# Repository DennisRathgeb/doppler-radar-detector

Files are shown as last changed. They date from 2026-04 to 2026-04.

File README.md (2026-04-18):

# Doppler Radar Detector

> 24 GHz radar that measures distance (FMCW) and speed (CW Doppler), streams a live spectrum to a touchscreen UI, bridges telemetry over WiFi, and fuses the radar result with camera-based angle-of-arrival detection on a desktop application. ZHAW PM4 team project, spring 2025.











## Block Diagram

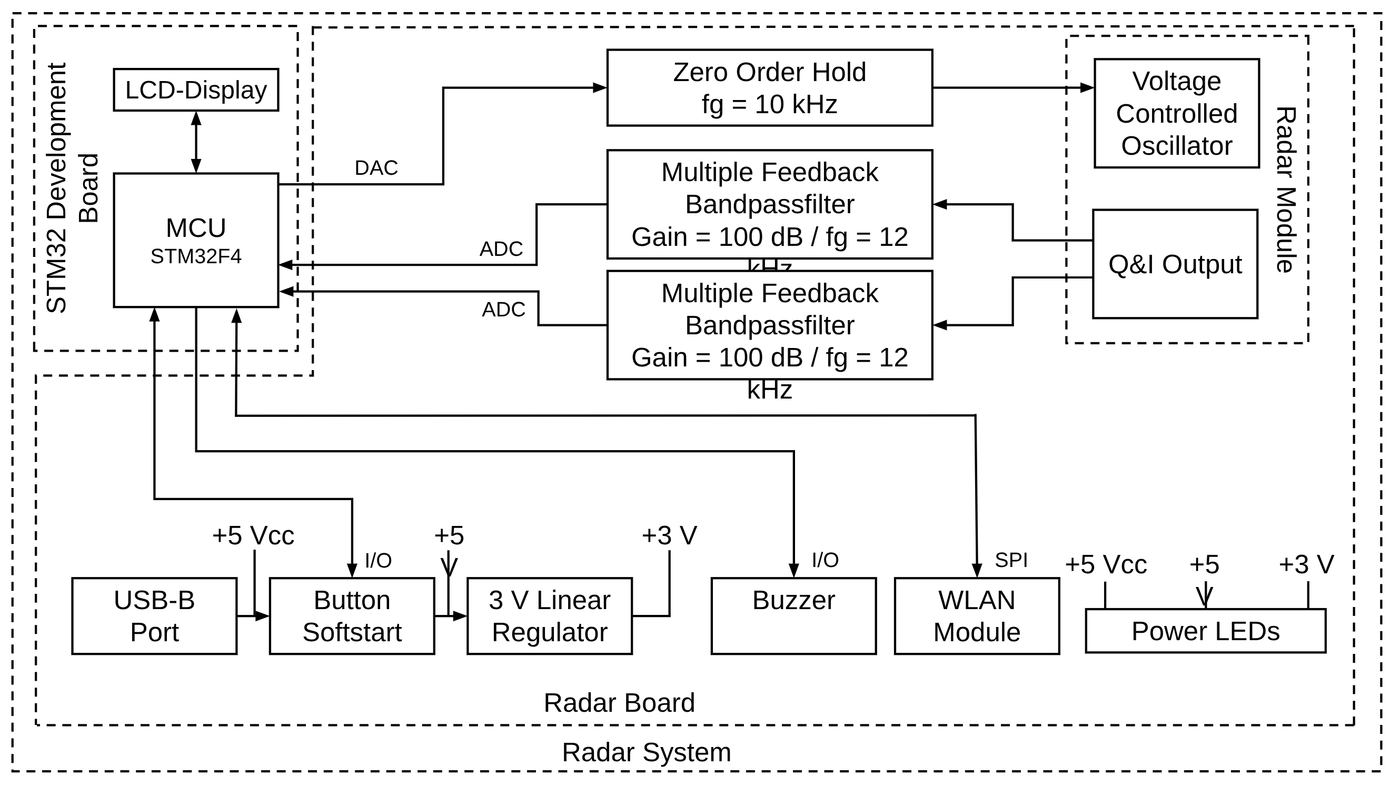
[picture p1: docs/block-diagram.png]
System block diagram


MCU-side signal flow:

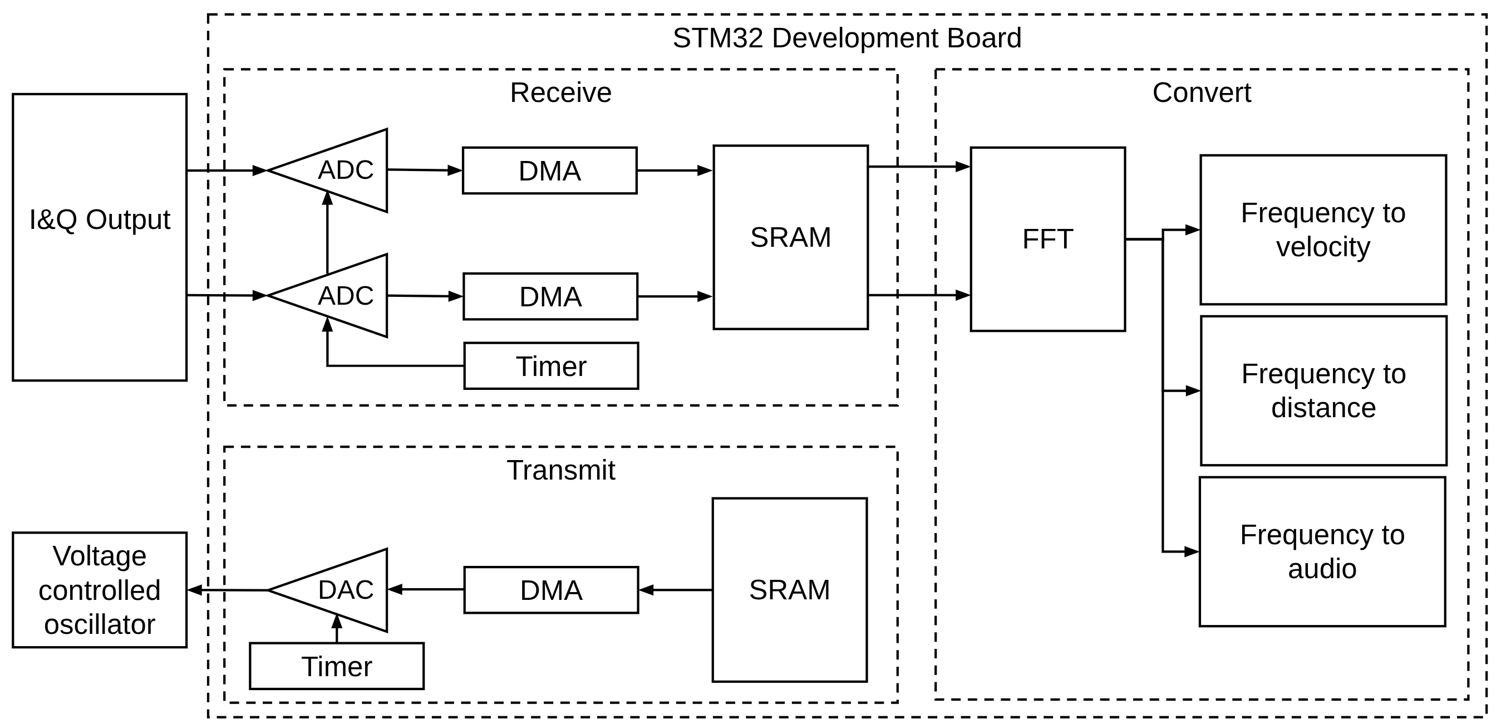
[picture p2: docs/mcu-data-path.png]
STM32 data path — I/Q → ADC → DMA → SRAM → FFT, and the transmit branch SRAM → DMA → DAC → VCO


Full schematic of the analog / radar board: [docs/schematic.pdf](docs/schematic.pdf).

## Highlights

- **Dual-mode 24 GHz RF front-end** — two radar modules, one CW (speed), one FMCW (distance).
- **Six-stage analog signal conditioning** (multi-feedback bandpass, ~58 dB gain at 7 kHz, I/Q channels in parallel).
- **DMA-driven dual-simultaneous ADC** feeding a **CMSIS-DSP `arm_cfft_f32`** with **ping-pong double-buffering** and SDRAM-backed FFT history — zero dropped samples under FreeRTOS.
- **TouchGFX live UI** — the FFT output buffer in SDRAM is the GUI's source buffer. No polling layer between processing and render.
- **ESP32 WiFi bridge over SPI** (STM32 master, ESP32 slave on HSPI, handshake line) → FastAPI backend.
- **YOLOv8 angle-of-arrival fusion** on the desktop — webcam + neural net → class + angle; radar → speed; Android GPS (UDP NMEA) → ground-truth reference.

## Repository Map

| Path | What's there |
|---|---|
| `hardware/kicad/` | KiCad schematic + PCB (V1, V3), exported PDF, component libraries |
| `hardware/simulations/` | LTSpice MF bandpass filter simulation |
| `hardware/calculations/`  | MATLAB: time-of-flight (`tof.m`), noise (`sigma.m`) |
| `hardware/python-tools/`  | Jupyter notebook for tolerance analysis |
| `hardware/pinout/` | STM32 pin assignments |
| `hardware/blockdiagram/`  | Source files for the system block diagram |
| `matlab/Bodeplot/` | Frequency-response analysis of the filter chain |
| `matlab/CW_Doppler/` | Reference signal-chain simulation (synthetic target → FFT → peak) |
| `firmware/stm32/` | STM32F429 firmware — Core, Drivers, Middlewares, TouchGFX, user modules (`measurement.c`, `vco.c`, `timing.c`, `esp.c`, ...), STM32CubeIDE project |
| `firmware/esp32/` | ESP-IDF project (WiFi STA + SPI slave bridge) |
| `backend/` | FastAPI backend (early stub) |
| `desktop-app/` | Python fusion app: YOLOv8 detection + Android GPS UDP listener + cv2 live overlay |
| `tests/hw-concept-tolerance/` | HW tolerance scripts |
| `docs/` | Concept report (PDF), block diagram, amplifier-stage test notes |

## Quickstart

### STM32 firmware

Requires **STM32CubeIDE** (any recent version). Either:

- Import the `STM32CubeIDE/` folder as an existing Eclipse project, or
- Open `firmware/stm32/Radar_v2.ioc` with STM32CubeMX and regenerate the project.

Build and flash to an **STM32F429 Discovery** board. Serial log on UART1.

### ESP32 firmware

Requires **ESP-IDF** (v5.x recommended). From `firmware/esp32/`:

```bash
idf.py set-target esp32
idf.py build
idf.py -p /dev/ttyUSB0 flash monitor
```

Before flashing, edit `main/wifi.c` and replace the placeholder `WIFI_SSID` / `WIFI_PASS` with your network credentials.

### FastAPI backend

```bash
cd backend
python3 -m venv .venv && source .venv/bin/activate
pip install -r requirements.txt
uvicorn main:app --reload
```

Note: the backend is an early scaffold.

### Desktop application

```bash
cd desktop-app
python3 -m venv .venv && source .venv/bin/activate
pip install -r requirements.txt
python collect_main.py
```

The first run auto-downloads the YOLOv8n weights (~6 MB) via `ultralytics`. For ground-truth speed reference, run an Android app that streams NMEA-0183 `$GPVTG` / `$GNVTG` sentences over UDP to port 5005 on your laptop. The app tolerates the GPS feed being absent.

## Credits

ZHAW PM4 team project, spring semester 2025. Authors: Dennis Rathgeb, Bryan Uhlmann, Benjamin Tschopp.

The original collaboration took place on ZHAW's internal GitHub instance; this public repository is a slimmed mirror.

## License

MIT — see [LICENSE](LICENSE).

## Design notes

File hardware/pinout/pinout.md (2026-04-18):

# STM32F429 Pin Assignments

## Sheet1

| STM32F429 Discovery board |  |  |  |  |  |  |  |  | hhrt@zhaw.ch | 2020-06-18 00:00:00 |  |
|---|---|---|---|---|---|---|---|---|---|---|---|
|  |  |  |  |  |  |  |  |  | Meaning of the colours: |  |  |
| Compiled by hhrt@zhaw.ch by consulting  the user manual of the evaluation board and the datasheet of the MCU |  |  |  |  |  |  |  |  | Pin is fully available |  |  |
|  |  |  |  |  |  |  |  |  | Pin available when SDRAM, Gyro resp. LED not used |  |  |
|  |  |  |  |  |  |  |  |  | GND and 3V supply |  |  |
|  |  |  |  |  |  |  |  |  | Pin is used by board function and is NOT available |  |  |
| ExtensionConnector P1 |  |  |  |  |  |  |  |  |  |  |  |
| Available
analog
functions | Was macht das bei uns??? Häää. Erklärung siehe unten | Available
alternate
functions | Board
function | Main
function | Pin | Pin | Main
function | Board
function | Available
alternate
functions | Available
analog
functions |  |
|  |  | 5V supply |  | 5V | 1 | 2 | 5V |  | 5V supply |  |  |
|  |  |  | SRRAM (A4) | PF4 | 3 | 4 | PF5 | SDRAM (A5) |  |  |  |
|  |  |  | SDRAM (A2) | PF2 | 5 | 6 | PF3 | SDRAM (A3) |  |  |  |
|  |  |  | SDRAM (A0) | PF0 | 7 | 8 | PF1 | SDRAM (A1) |  |  |  |
|  |  |  | OSC32_IN | PC14 | 9 | 10 | PC15 | OSC32_OUT |  |  |  |
|  |  | TIM9_CH2, SPI4_MOSI, SAI1_SD_A |  | PE6 | 11 | 12 | PC13 |  |  |  | SIG_SEL |
|  |  | SPI4_NSS, SAI1_FS_A |  | PE4 | 13 | 14 | PE5 |  | TIM9_CH1 , SPI4_MISO,  SAI1_SCK_A |  |  |
|  |  | SPI4_SCK, SAI1_MCLK_A |  | PE2 | 15 | 16 | PE3 |  | SAI1_SD_B |  |  |
|  |  |  | SDRAM (NBL0) | PE0 | 17 | 18 | PE1 | SDRAM (NBL1) |  |  |  |
|  |  |  | LCD | PB8 | 19 | 20 | PB9 | LCD |  |  |  |
|  |  |  | BOOT0 | BOOT0 | 21 | 22 | VDD |  |  |  |  |
|  |  |  | SDRAM (SDNE1) | PB6 | 23 | 24 | PB7 |  | TIM4_CH2, I2C1_SDA, USART1_RX |  |  |
|  | SPI3_MISO | TIM3_CH1,SPI1_MISO, SPI3_MISO, I2S3EXT_SD |  | PB4 | 25 | 26 | PB5 | SDRAM (SDCKE1) |  |  |  |
|  |  |  | SDRAM (SDNCAS) | PG15 | 27 | 28 | PB3 | SWO |  |  |  |
|  |  | SPI6_SCK, USART6_CTS (with LED indicator) | LED GREEN, LD3 | PG13 | 29 | 30 | PG14 | LED RED, LD4 | SPI6_MOSI, USART6_TX (with LED indicator) |  |  |
|  |  |  | LCD | PG11 | 31 | 32 | PG12 | LCD |  |  |  |
|  |  | USART6_RX |  | PG9 | 33 | 34 | PG10 | LCD |  |  |  |
|  |  | USART2_CK |  | PD7 | 35 | 36 | PD6 | LCD |  |  |  |
|  |  | USART2_TX |  | PD5 | 37 | 38 | PD4 |  | USART2_RTS |  |  |
|  |  |  | LCD | PD3 | 39 | 40 | PD2 |  | TIM3_ETR |  |  |
|  |  | CAN1_TX | SDRAM (D3) | PD1 | 41 | 42 | PD0 | SDRAM (D2) | CAN1_RX |  |  |
|  | SPI3_MOSI | SPI3_MOSI, I2S3_SD, USART3_CX, UART5_TX |  | PC12 | 43 | 44 | PC11 |  | I2S3EXT_SD, SPI3_MISO,USART3_RX, UART4_RX |  |  |
|  | SPI3_SCK/SPI3_NSS |  | LCD | PC10 | 45 | 46 | PA15 | TOUCH |  |  | SPI_NSS |
|  |  |  | SWCLK | PA14 | 47 | 48 | PA13 | SWDIO |  |  |  |
|  |  |  | LCD | PA12 | 49 | 50 | PA11 | LCD |  |  |  |
|  |  |  | USART1_RX (VCP) | PA10 | 51 | 52 | PA9 | USART1_TX (VCP) |  |  |  |
|  |  |  | I2C_EXT, TOUCH | PA8 | 53 | 54 | PC9 | I2C_EXT, TOUCH |  |  |  |
|  |  | TIM3_CH3, TIM8_CH3, USART6_CK |  | PC8 | 55 | 56 | PC7 | LCD |  |  |  |
|  |  |  | LCD | PC6 | 57 | 58 | PG8 | SDRAM (SDCLK) |  |  |  |
|  |  |  | LCD | PG7 | 59 | 60 | PG6 | LCD |  |  |  |
|  |  |  | SDRAM (BA1) | PG5 | 61 | 62 | PG4 | SDRAM (BA0) |  |  |  |
|  |  |  |  | GND | 63 | 64 | GND |  |  |  |  |
| Extension Connector P2 |  |  |  |  |  |  |  |  |  |  |  |
| Available
analog
functions |  | Available
alternate
functions | Board
function | Main
function | Pin | Pin | Main
function | Board
function | Available
alternate
functions | Available
analog
functions |  |
|  |  | 3V supply |  | 3V | 1 | 2 | 3V |  | 3V supply |  |  |
| ADC3_IN4 | Buzzer TIM10_CH1 | TIM10_CH1, SPI5_NSS, SAI1_SD_B, UART7_RX |  | PF6 | 3 | 4 | NC |  |  |  |  |
| ADC3_IN6 |  | SPI5_MISO, SAI1_SCK_B, TIM13_CH1 | GYRO (MISO) | PF8 | 5 | 6 | PF7 | LCD, GYRO SCL |  |  |  |
|  |  |  | LCD | PF10 | 7 | 8 | PF9 | LCD, GYRO |  |  |  |
|  |  |  | OSC_OUT | PH1 | 9 | 10 | PH0 | OSC_IN |  |  |  |
|  |  |  |  | GND | 11 | 12 | NRST | NRST |  |  |  |
| ADC123_IN11 | SIGNAL Q ADC1 |  | GYRO (CS) | PC1 | 13 | 14 | PC0 | SDRAM (SDNWE) |  |  |  |
| ADC123_IN13 | SIGNAL I ADC2 | SPI2_MOSI, I2A2_SD |  | PC3 | 15 | 16 | PC2 | LCD |  |  |  |
|  |  |  | GYRO (INT1) | PA1 | 17 | 18 | PA0 | PushButton |  |  |  |
|  |  |  | LCD | PA3 | 19 | 20 | PA2 | GYRO (INT2) |  |  |  |
| ADC12_IN5, DAC_OUT2 | Radar VCO DAC_OUT2 | TIM2_CH1, TIM2_ETR, TIM8_CH1N, SPI1_SCK |  | PA5 | 21 | 22 | PA4 | LCD |  |  |  |
|  |  |  | I2C_EXT | PA7 | 23 | 24 | PA6 | LCD |  |  |  |
|  |  |  | USB | PC5 | 25 | 26 | PC4 | USB |  |  |  |
|  |  |  | LCD | PB1 | 27 | 28 | PB0 | LCD |  |  |  |
|  |  |  |  | GND | 29 | 30 | PB2 (BOOT1) | BOOT1 |  |  |  |
|  |  |  | SDRAM (A6) | PF12 | 31 | 32 | PF11 | SDRAM (SDNRAS) |  |  |  |
|  |  |  | SDRAM (A8) | PF14 | 33 | 34 | PF13 | SDRAM (A7) |  |  |  |
|  |  |  | SDRAM (A10) | PG0 | 35 | 36 | PF15 | SDRAM (A9) |  |  |  |
|  |  | TIM1_ETR, UART7_Rx | SDRAM (D4) | PE7 | 37 | 38 | PG1 | SDRAM (A11) |  |  |  |
|  |  | TIM1_CH1, FMC_D6 | SDRAM (D6) | PE9 | 39 | 40 | PE8 | SDRAM (D5) | TIM1_CH1N, UART7_Tx |  |  |
|  |  | TIM1_CH2, SPI4_NSS | SDRAM (D8) | PE11 | 41 | 42 | PE10 | SDRAM (D7) | TIM1_CH2N, FMC_D7 |  |  |
|  |  | TIM1_CH3, SPI4_MISO | SDRAM (D10) | PE13 | 43 | 44 | PE12 | SDRAM (D9) | TIM1_CH3N, SPI4_SCK |  |  |
|  |  | TIM1_BKIN | SDRAM (D12) | PE15 | 45 | 46 | PE14 | SDRAM (D11) | TIM1_CH4, SPI4_MOSI |  |  |
|  |  |  | LCD | PB11 | 47 | 48 | PB10 | LCD |  |  |  |
|  |  |  | USB | PB13 | 49 | 50 | PB12 | USB |  |  |  |
|  |  |  | USB | (PB15) | 51 | 52 | (PB14) | USB |  |  |  |
|  |  | USART3_RX | SDRAM (D14) | PD9 | 53 | 54 | PD8 | SDRAM (D13) | USART3_TX |  |  |
|  | ESP_EN |  | LCD | PD11 | 55 | 56 | PD10 | SDRAM (D15) | USART3_CK |  |  |
|  |  |  | LCD | PD13 | 57 | 58 | PD12 | LCD |  |  |  |
|  |  | TIM4_CH4 | SDRAM (D1) | PD15 | 59 | 60 | PD14 | SDRAM (D0) | TIM4_CH3 |  |  |
|  | Input Enable PCB |  |  | PG3 | 61 | 62 | PG2 |  |  |  | Output Enable PCB |
|  |  |  |  | GND | 63 | 64 | GND |  |  |  |  |

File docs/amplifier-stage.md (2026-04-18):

# Hardware Amplifier Stage Test Preset

## Test Setup

- **Device Under Test (DUT):** Hardware Amplifier Stage
- **Test Equipment:**
  - Signal Generator: FY6900
  - Oscilloscope: Sigilent SDS824
  - Power Supply: Basetech BT-305 & USB from Laptop

## Test Cases

### 1. Static Tests

- **Objective:** Verify the amplifier's behavior without input signals.
- **Procedure:**
  - Power on the amplifier.
  - Measure and record the input Voltage of each Stage
  - Visual inspection of IC Orientation and solder points

### 2. Frequency Response Tests

#### a. No Input Signal

- **Objective:** Verify the amplifier's output with no input signal.
- **Procedure:**
  - Ensure no input signal is applied.
  - Measure and record the output noise level.

#### c. Input Signal at 10,000 kHz

- **Objective:** Test the amplifier's response at 10,000 kHz.
- **Procedure:**
  - Apply a 10,000 kHz sine wave to the input.
  - Measure and record the output amplitude and phase.

### 3. Bode Plot

- **Objective:** Generate a Bode plot to analyze the frequency response. from 100Hz to 100kHz
- **Procedure:**
  - Sweep the input frequency across the amplifier's operating range.
  - Record the gain and phase shift at each frequency.
  - Plot the results to visualize the frequency response.

## Results

### 1. Static Tests

**Input Voltage `PASS`**
| **Description** | **Test Point** | **Value** |
|---|---|---|
|Offset OpAmp 1|Opamp 1 Pin 8 | 3.289V |
|Offset Voltage OpAmp 2|Opamp 2 Pin 8| 3.289V |
|Offset Voltage OpAmp 3|Opamp 3 Pin 8| 3.289V |

**Offset Voltage `PASS`**
| **Description** | **Test Point** | **Value** |
|---|---|---|
|Offset OpAmp 1|Opamp 1 Pin 5 | 1.64V |
|Offset Voltage OpAmp 2|Opamp 2 Pin 5| 1.64V |
|Offset Voltage OpAmp 3|Opamp 3 Pin 5| 1.64V |

**Visual Inspection `PASS`**
| **Description** | **Result** |
|---|---|
| OpAmp 1 IC | Pass |
| OpAmp 2 IC | Pass |
| OpAmp 3 IC | Pass |
| Resistors Check | Pass |
| Capacitors Check | Pass |

### 2. Frequency Response Tests

#### No Input Signal

**Connections**

- TP 2 is used for GND
- Signal Input(TP3& TP4) connected to GND
- TP 5 & 6 is signal OUTPUT

**Result**
Aquire Mode with 40 Sequences was used:
**TP5**
| **Description** | **Value** | **Result** |
| --- | --- | --- |
| Mean Voltage | 1.65 V | `PASS` |
| Peak-to-Peak Voltage | < 10 mV | `PASS` |
| Frequency | > 1 MHz | `PASS` |

**TP6**
| **Description** | **Value** | **Result** |
| --- | --- | --- |
| Mean Voltage | 1.65 V | `PASS` |
| Peak-to-Peak Voltage | < 20 mV | `PASS` |
| Frequency | > 1 MHz | `PASS` |

#### 10kHz Input Signal

**Connections**

- TP 1 & 2 is used for GND
- Signal Input (TP3 & 4) connected to Signal
- TP 7 & 9 is signal OUTPUT stage 1
- TP 8 & 10 is signal OUTPUT stage 2
- TP 5 & 6 is signal OUTPUT stage 2
  > **signal**: 1kHz, 0.01V (resistor divider) , 1.64V Offset
  > **measure**: Aquire Mode with 40 seq, 1X Probe, DC Coupling, 1MOhm

**Result Stage 1**
**I: TP6**
| **Description** | **Value** | **Result** |
| --- | --- | --- |
| Peak-to-Peak Voltage | 60mV @1V | **`FAIL`** |
| Frequency | 10kHz | `PASS` |

**Q: TP7**
| **Description** | **Value** | **Result** |
| --- | --- | --- |
| Peak-to-Peak Voltage | 30mV | `PASS` |
| Frequency | 10kHz | `PASS` |

**Result Stage 2**
**I: TP10**
| **Description** | **Value** | **Result** |
| --- | --- | --- |
| Peak-to-Peak Voltage | 110mV @ 1V | **`FAIL`** |
| Frequency | 10kHz | `PASS` |

**Q: TP8**
| **Description** | **Value** | **Result** |
| --- | --- | --- |
| Peak-to-Peak Voltage | 150mV | `PASS` |
| Frequency | 10kHz | `PASS` |

**Result Stage 3**
**I: TP6**
| **Description** | **Value** | **Result** |
| --- | --- | --- |
| Peak-to-Peak Voltage | 870mV @ 1V | **`FAIL`** |
| Frequency | 10kHz | `PASS` |

**Q: TP5**
| **Description** | **Value** | **Result** |
| --- | --- | --- |
| Peak-to-Peak Voltage | 1.23V | `PASS` |
| Frequency | 10kHz | `PASS` |

> **TODO NOTE: CHECK I Stage sths wrong here.**

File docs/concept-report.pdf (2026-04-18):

## T-ISC-ET-PM4 FS 2025

# Concept Design Report of Radar System 3000

## Rathgeb Dennis, 20-917-944 Tschopp Benjamin, 14-781-92 Uhlmann Bryan Marc, 14-615-21

## April 18, 2026

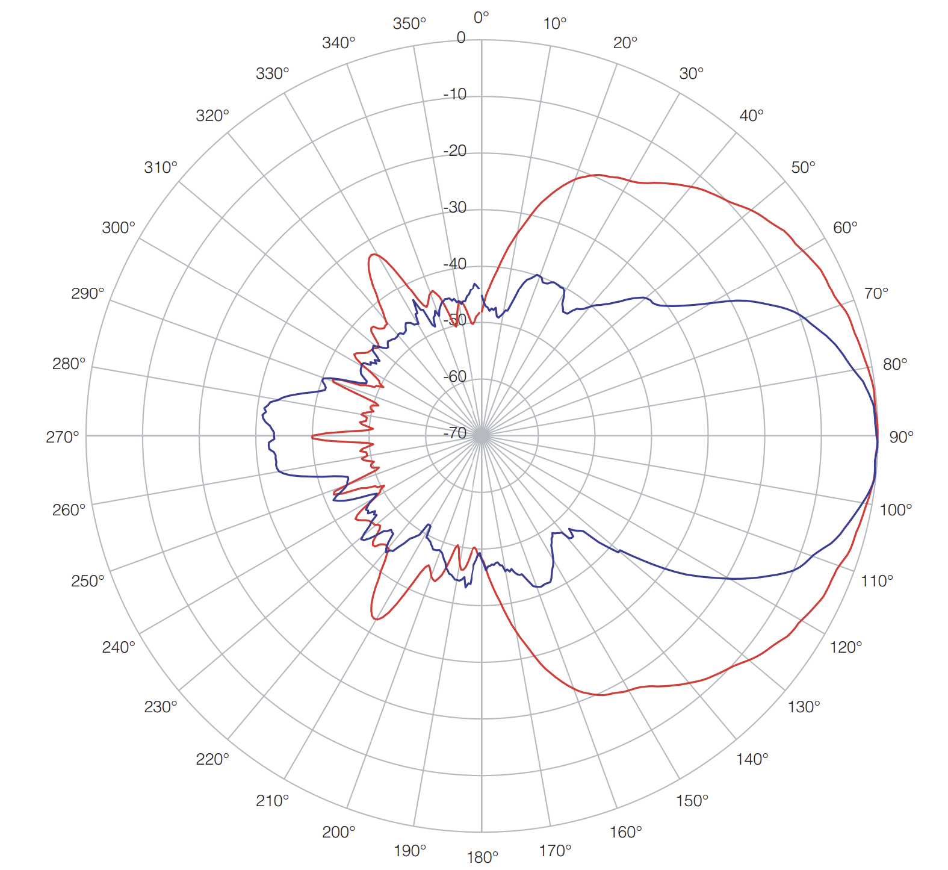
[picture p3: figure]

PM4: Radar System 3000
Concept Design Report

## Abstract

This document presents the concept of the Radar System 3000. The Radar System 3000 will be designed with a microcontroller and a radar module. Based on the pulse echo technique the Radar System 3000 utilizes Frequency Modulated Continuous Wave (FMCW) modulation to measure the distance. With the help of the Doppler effect and a Continuous Wave (CW) the speed of objects will be determent. The Radar System 3000 is designed to detect car-sized objects at a range of up to 30 meters with a speed of up to 300 km/h. This report outlines the motivation, requirements, and technical concepts covering hardware, software, user interface, and additional features.

2

# Table of Contents

3

## 1 Introduction

The proposed Radar System 3000 will be able to measure an object’s distance up to 30 meters and speed up to 300 km/h. The integration of the STM32F4 microcontroller (MCU) unit ensures flexibility and high processing power. The project is valuable because of it’s potential to provide real-time object detection at an extended range.

### 1.1 General Principle

The Radar System 3000 operates by transmitting electromagnetic waves and analyzing their reflections from objects. Figure 1 shows this basic principle. By measuring the time a transmitted signal takes to return, distance can be determined. A moving object causes a frequency shift in the reflection (Doppler effect), which reveals its velocity.

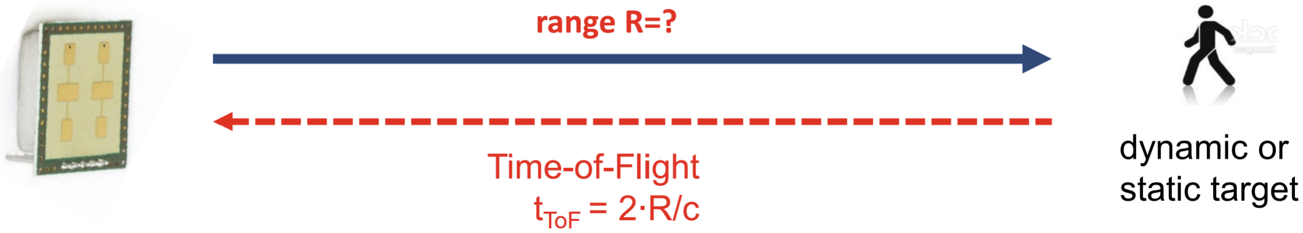
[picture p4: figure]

Figure 1: The basic principle of Radar Systems.

The 24GHz radar module allows for different techniques to be deployed: Frequency Modulated Continuous Wave (FMCW) for measuring object distance and Continuous Wave (CW) for determining object speed.

### 1.2 FMCW Radar

The FMCW radar will transmit a frequency modulated signal in the form of a linear chirp. The transmitted wave gradually sweeps through a range of frequencies over a known time period. When this signal is reflected off an object, the received wave is delayed relative to the transmitted wave. The difference in frequency between the transmitted and received signals, known as the beat frequency, is proportional to the distance of the object.
FMCW radar offers several advantages over conventional pulsed radar, including:
- Accurate range resolution over measured distance.
- Simultaneous distance and speed measurement by analyzing the beat frequency and it’s phase shift over time.
- Operate with lower peak power. More energy efficient and suitable for embedded applications.

By leveraging these benefits, the proposed radar sensor module enables accurate and efficient detection of objects within a range of 30 meters, making it suitable for automotive and industrial applications.

### 1.3 CW Radar

Additionally, due to the Doppler effect, any motion of the object relative to the radar causes a frequency shift, which can be used to calculate its velocity.
By leveraging these benefits, the proposed radar sensor module enables accurate and efficient detection of objects within a range of 30 meters, making it suitable for automotive and industrial applications.
1 Introduction | 4

### 1.4 Requirements

The Radar Board is required to fulfill the following specifications:

- Detect car-sized objects from a distance of 1 m up to 30 m.
- Measure car-sized object’s speed from 10 km/h up to 300 km/h.
- Measuring distance using FMCW modulation.
- Measuring speed using CW.
- Robust signal processing algorithm.
- User-friendly interface for configuration and monitoring.

### 1.5 Additional Features

The following functions are optional:

- Measuring speed using FMCW modulation.
- Buzzer for audible feedback.
- Transmitting data over WLAN for a integration with an Internet of Things Network (IoT) or desktop application.
1 Introduction | 5

## 2 Hardware Concept

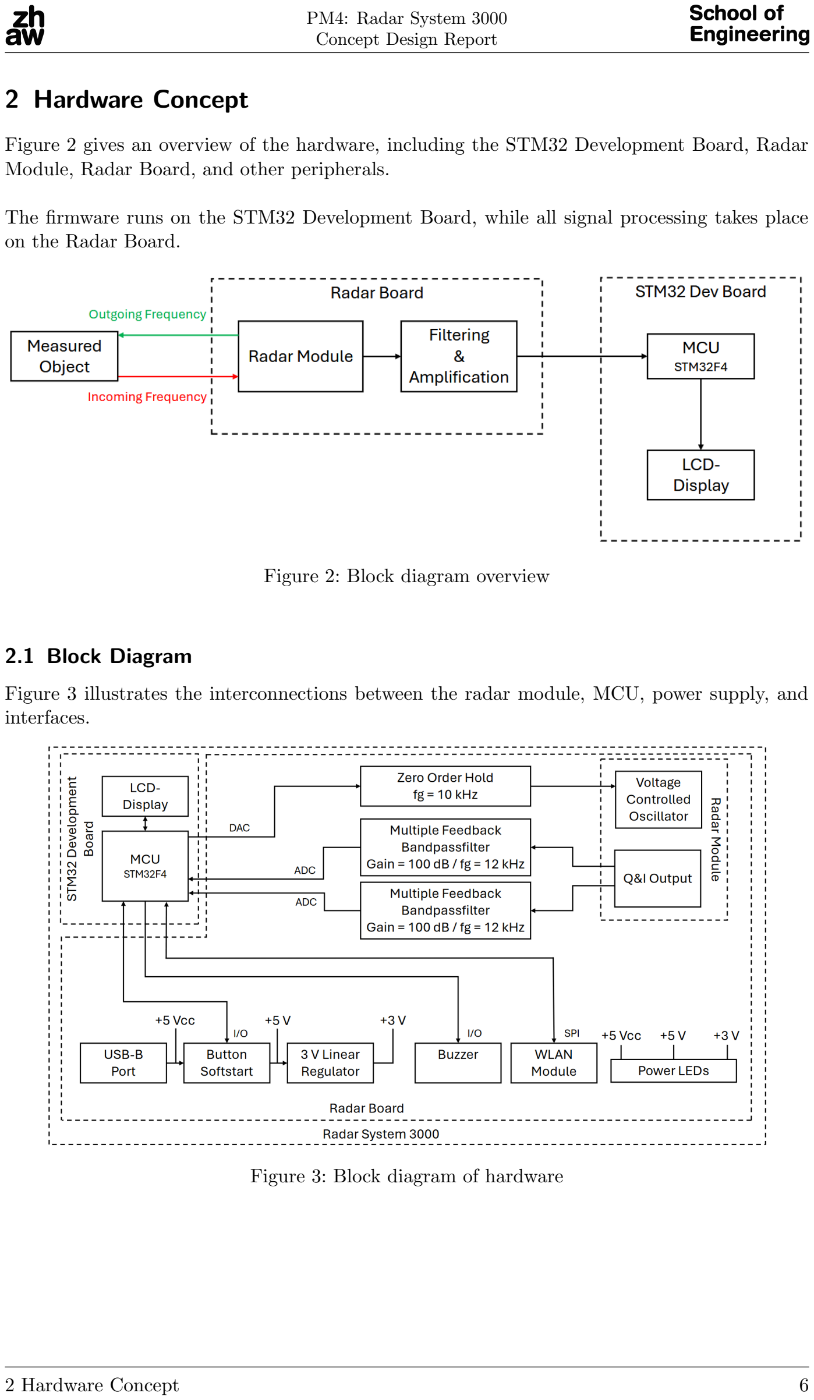
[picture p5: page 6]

Figure 2 gives an overview of the hardware, including the STM32 Development Board, Radar Module, Radar Board, and other peripherals.

The firmware runs on the STM32 Development Board, while all signal processing takes place on the Radar Board.

Figure 2: Block diagram overview

### 2.1 Block Diagram

Figure 3 illustrates the interconnections between the radar module, MCU, power supply, and interfaces.

Figure 3: Block diagram of hardware

2 Hardware Concept | 6

## 3 Software Concept

The software will implement:

- FMCW and CW signal processing algorithms for extracting distance and speed information.
- Real-time data acquisition and filtering techniques.
- Precise frequency control and regulation of the radar module.
- User interface management.
- Error detection and handling mechanisms to enhance reliability.

### 3.1 Firmware Block Diagram

Figure 4 illustrates the processing stages from radar signal acquisition to output data presentation.

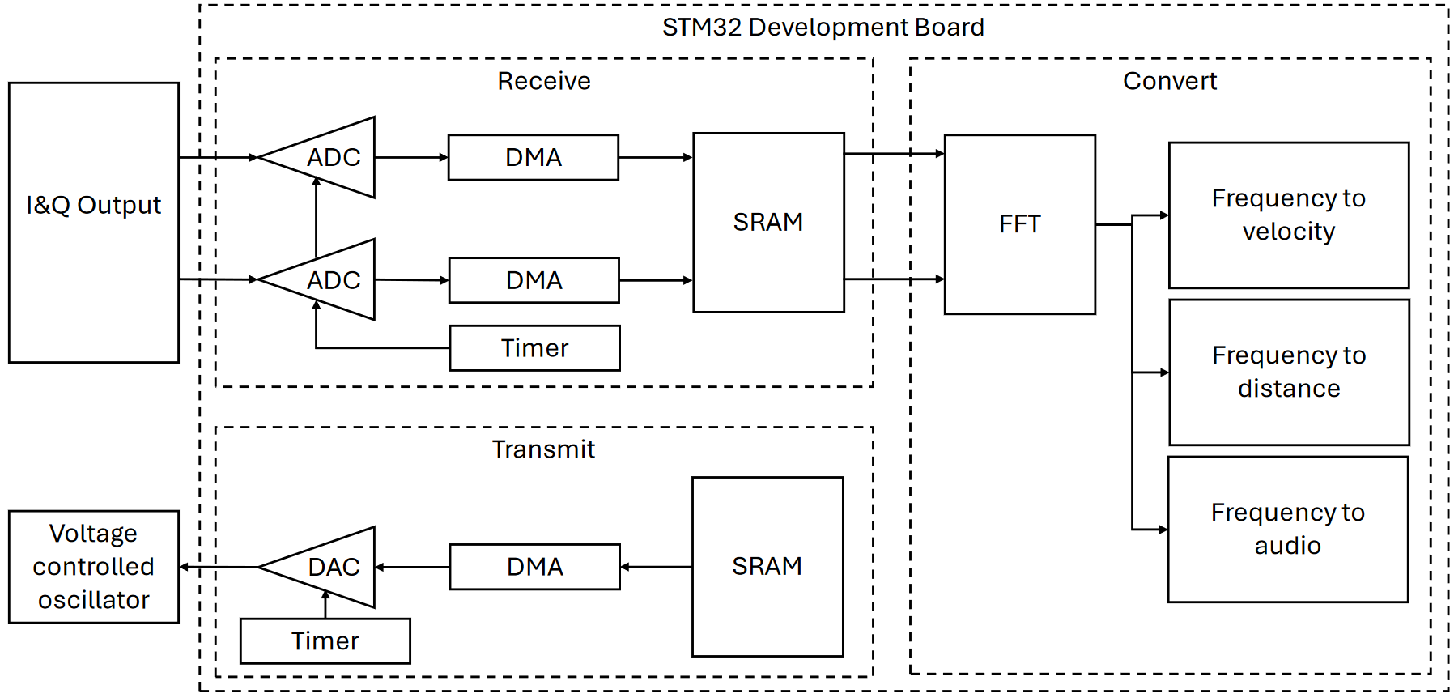
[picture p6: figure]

Figure 4: Block diagram of hardware

3 Software Concept | 7

## 4 User Interface

To enhance the user experience, the system includes multiple feedback mechanisms for local and remote interaction. A liquid crystal display provides real-time visualization of key radar measurements, while a WLAN module enables wireless communication with IoT devices, desktop applications, or mobile apps. Additionally, an integrated buzzer offers audible alerts when specific thresholds are exceeded, such as detecting an object at a critical speed. This combination of visual, auditory, and wireless feedback mechanisms improves the usability and functionality of the radar module in various application scenarios.

### 4.1 LCD Display

The Radar System 3000 includes a touch sensitive LCD display to provide real-time feedback and system status information to the user. The display is used to present key radar measurements, such as detected object distance and speed. Additionally, it will show system status messages, error warnings, or configuration settings.
The main functions of the LCD display include:
- Real-time Data Visualization: Displaying detected object parameters such as range and speed.
- Status Indications: Showing connectivity status and error messages.
- User Interaction: Providing visual feedback during parameter configuration and calibration.

The LCD display ensures local usability of the radar system, even when no wireless connection is available.

### 4.2 WLAN Module

The WLAN module serves as a crucial component for enabling wireless communication between the Radar System 3000 and various IoT devices, desktop applications, or mobile applications. By integrating WLAN functionality, the system allows real-time transmission of processed radar data to remote clients, facilitating monitoring, logging, and further analysis.

The key functionalities of the WLAN module will include:

- Wireless data transmission: The radar module can send distance and velocity measurements to an external device via a secure wireless connection.
- Integration with IoT platforms: The transmitted data could be processed and visualized on IoT dashboards, cloud services, or custom applications.
- Remote configuration and control: Users can adjust radar parameters, set detection thresholds, and update firmware remotely via a web interface or mobile app.

By incorporating this module from the outset, future enhancements in wireless communications will be seamlessly integrated, ensuring scalability and adaptability to evolving requirements.

4 User Interface | 8

## 5 List of Figures

1 | The basic principle of Radar Systems | | 4
2 | Block diagram overview | | 6
3 | Block diagram of hardware | | 6
4 | Block diagram of hardware | | 7

9

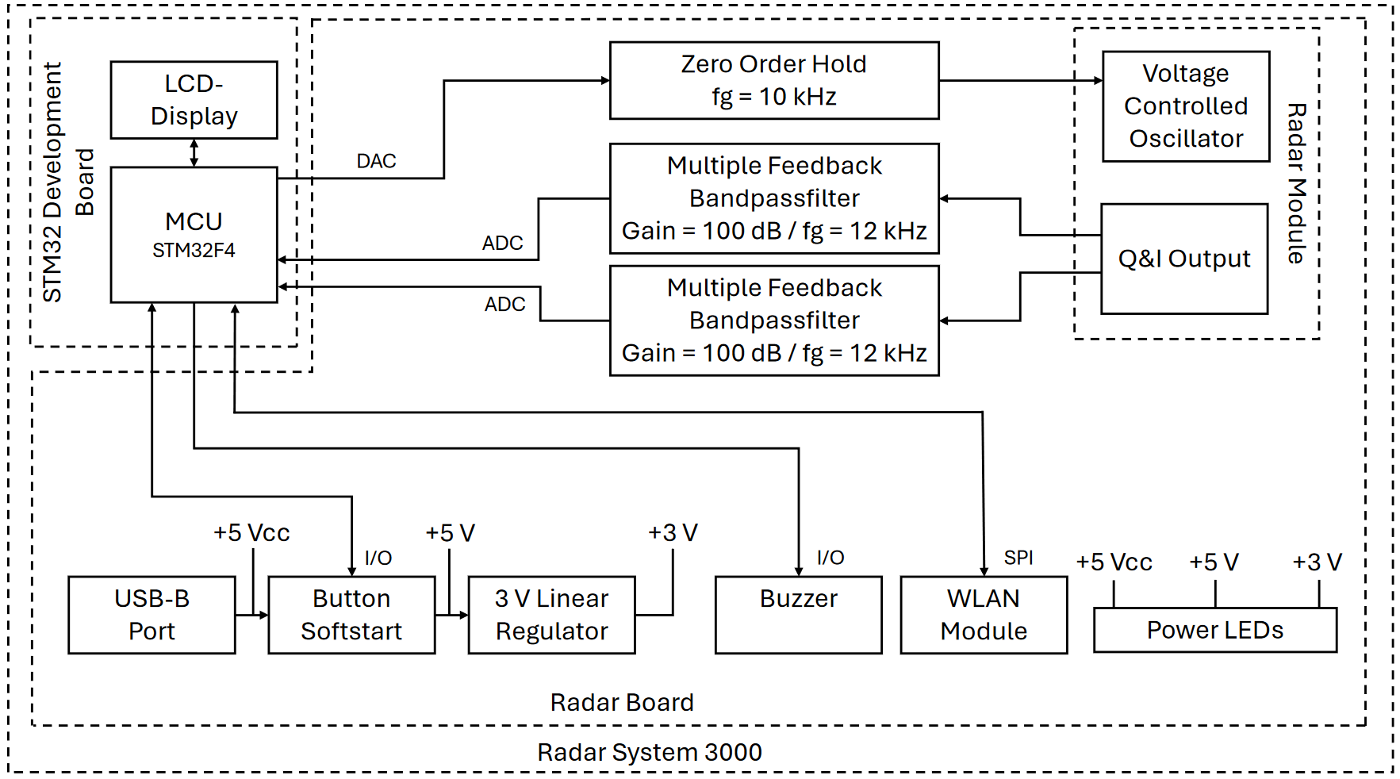
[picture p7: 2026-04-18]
hardware/blockdiagram/HW_Design.png

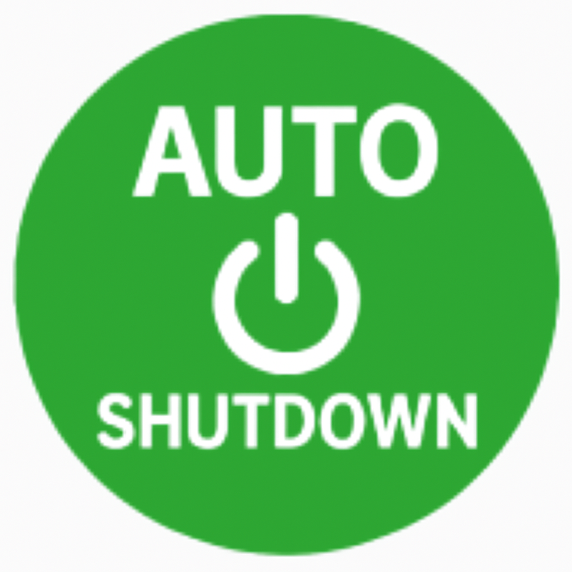
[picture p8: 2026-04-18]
docs/autoshutdown.png

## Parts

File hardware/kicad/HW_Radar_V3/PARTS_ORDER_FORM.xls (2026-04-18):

Sammel- Bestellungen Dienstag Morgen (Distrelec, Farnell, Mouser), Einreichen bis Montag Abend |  |  |  | Achtung: Vor der Bestellung bitte unbedingt Lieferbarkeit prüfen. - Art- Nr. ohne Leerzeichen eintragen. - Mouser und Digikey nur wenn bei Distr./Farnell nicht erhätlich
Lieferant | ArtNr. | Anzahl | Typ, Bezeichnung | EinzelPreis | Gesamtpreis | spätester Bestell-termin | Bemerkungen | Besteller (Kurzzeichen) | bestellt Datum | Termin Nach- lieferung
Distrelec |  |  |  |  | 0.00
Distrelec |  |  |  |  | 0.00
Distrelec |  |  |  |  | 0.00
Distrelec |  |  |  |  | 0.00
Distrelec |  |  |  |  | 0.00
Distrelec |  |  |  |  | 0.00
Distrelec |  |  |  |  | 0.00
Distrelec |  |  |  |  | 0.00
Distrelec |  |  |  |  | 0.00
Distrelec |  |  |  |  | 0.00
Distrelec |  |  |  |  | 0.00
Distrelec |  |  |  |  | 0.00
Lieferant | ArtNr. | Anzahl | Typ, Bezeichnung | EinzelPreis | Gesamtpreis | spätester Bestell-termin | Bemerkungen | Besteller (Kurzzeichen) | bestellt Datum | Termin Nach- lieferung
Farnell |  |  |  | 0.79 | 0.00
Farnell |  |  |  |  | 0.00
Farnell |  |  |  |  | 0.00
Farnell |  |  |  |  | 0.00
Farnell |  |  |  |  | 0.00
Farnell |  |  |  |  | 0.00
Farnell |  |  |  |  | 0.00
Farnell |  |  |  |  | 0.00
Farnell |  |  |  |  | 0.00
Farnell |  |  |  |  | 0.00
Farnell |  |  |  |  | 0.00
Farnell |  |  |  |  | 0.00
Farnell |  |  |  |  | 0.00
Farnell |  |  |  |  | 0.00
Lieferant | ArtNr. | Anzahl | Typ, Bezeichnung | EinzelPreis | Gesamtpreis | spätester Bestell-termin | Bemerkungen | Besteller (Kurzzeichen) | bestellt Datum | Termin Nach- lieferung
Mouser |  |  |  |  | 0.00
Mouser |  |  |  |  | 0.00
Mouser |  |  |  |  | 0.00
Mouser |  |  |  |  | 0.00
Mouser |  |  |  |  | 0.00
Mouser |  |  |  |  | 0.00
Mouser |  |  |  |  | 0.00
Mouser |  |  |  |  | 0.00
Mouser |  |  |  |  | 0.00
Mouser |  |  |  |  | 0.00
Mouser |  |  |  |  | 0.00
Mouser |  |  |  |  | 0.00
Mouser |  |  |  |  | 0.00
Mouser |  |  |  |  | 0.00
Mouser |  |  |  |  | 0.00
Mouser |  |  |  |  | 0.00
Mouser |  |  |  |  | 0.00
Mouser |  |  |  |  | 0.00
Mouser |  |  |  |  | 0.00
Mouser |  |  |  |  | 0.00
Mouser |  |  |  |  | 0.00
Mouser |  |  |  |  | 0.00
Mouser |  |  |  |  | 0.00
Mouser |  |  |  |  | 0.00
Mouser |  |  |  |  | 0.00
Lieferant | ArtNr. | Anzahl | Typ, Bezeichnung | EinzelPreis | Gesamtpreis | spätester Bestell-termin | Bemerkungen | Besteller (Kurzzeichen) | bestellt Datum | Termin Nach- lieferung
Digikey | 296-18598-1-ND | 6 | TS5A23159DGSR | 0.63 | 3.78
Digikey | 1965-ESP32-S3-WROOM-1-N16R8TR-ND | 3 | ESP32-S3-WROOM-1 N16R8 | 6.50 | 19.50
Digikey | TC2050-IDC-NL-ND | 1 | Programming connector Jtag | 39.00 | 39.00
Digikey | 1048-TC2050-CLIP-3PACK-ND | 1 | programming cable retaining clips | 18.00 | 18.00
Digikey |  |  |  |  | 0.00
Digikey |  |  |  |  | 0.00
Digikey |  |  |  |  | 0.00
Digikey |  |  |  |  | 0.00
Digikey |  |  |  |  | 0.00
Digikey |  |  |  |  | 0.00
Digikey |  |  |  |  | 0.00
Digikey |  |  |  |  | 0.00
Digikey |  |  |  |  | 0.00
Digikey |  |  |  |  | 0.00
Digikey |  |  |  |  | 0.00
Digikey |  |  |  |  | 0.00
Digikey |  |  |  |  | 0.00
Digikey |  |  |  |  | 0.00
Digikey |  |  |  |  | 0.00
Digikey |  |  |  |  | 0.00
Digikey |  |  |  |  | 0.00

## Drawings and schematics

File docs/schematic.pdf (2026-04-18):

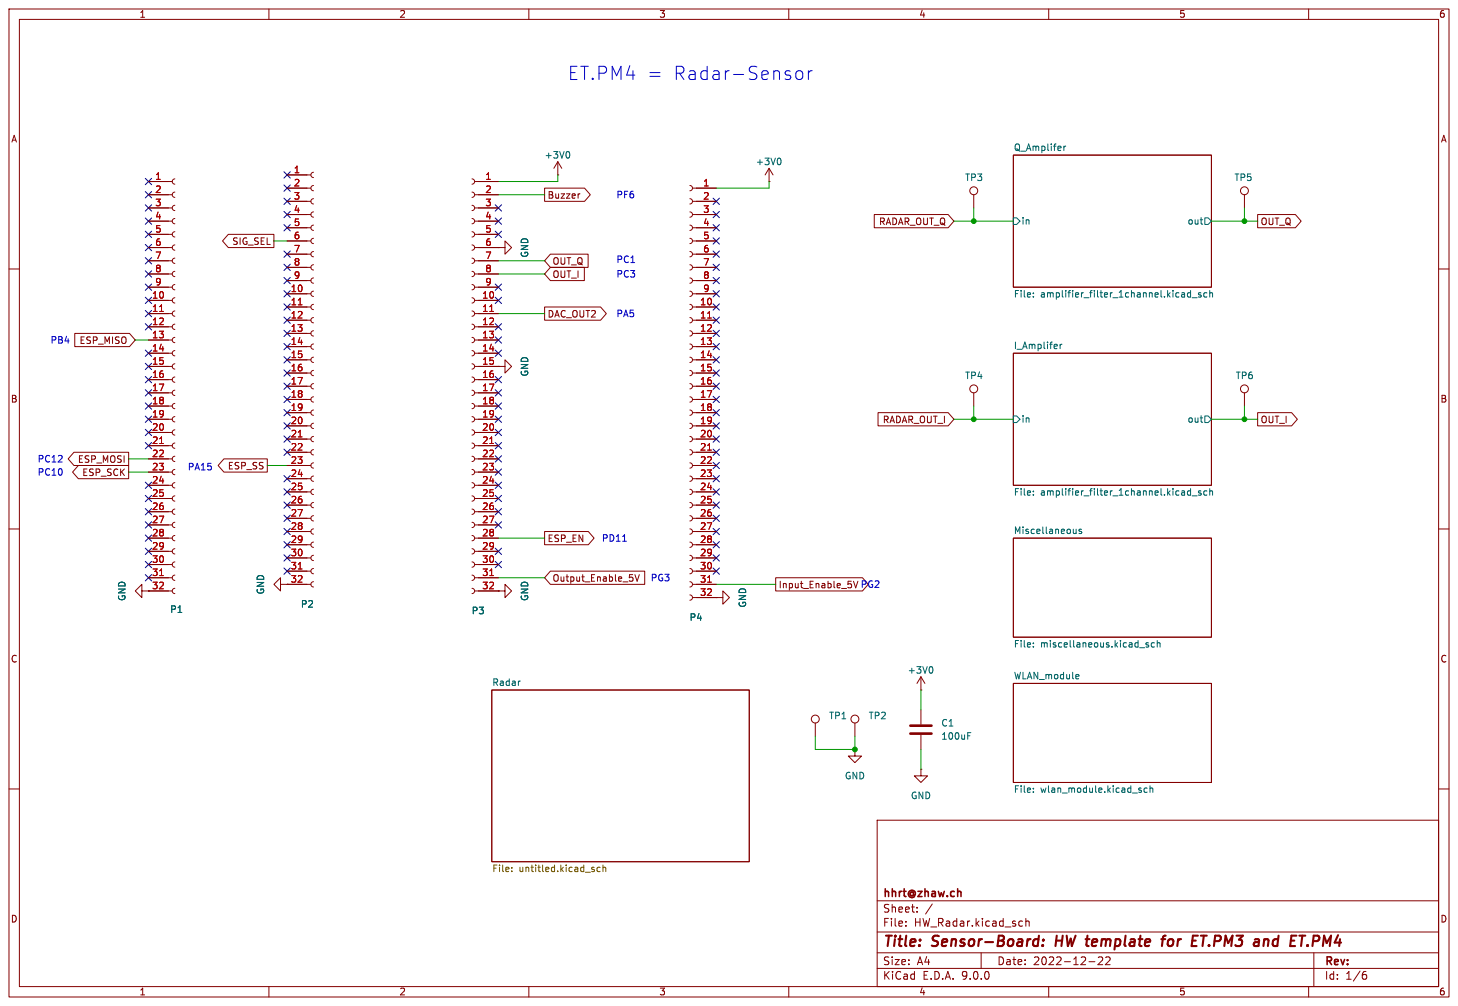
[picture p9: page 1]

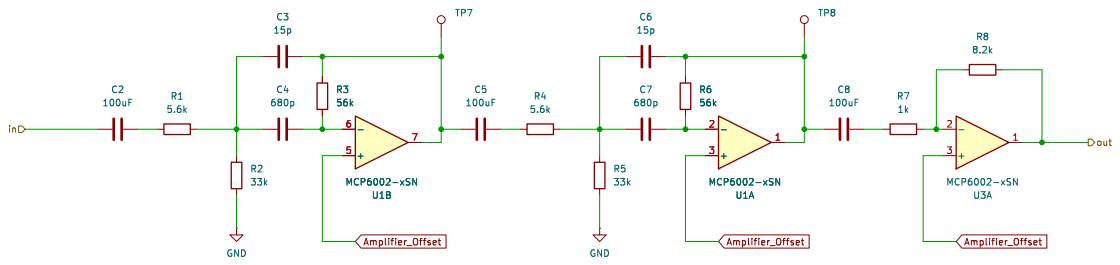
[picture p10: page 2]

hhrt@zhaw.ch
File: amplifier_filter_1channel.kicad_sch Sheet: /Q_Amplifer/
Id: 3/6 Title: Amplifiers and Filters

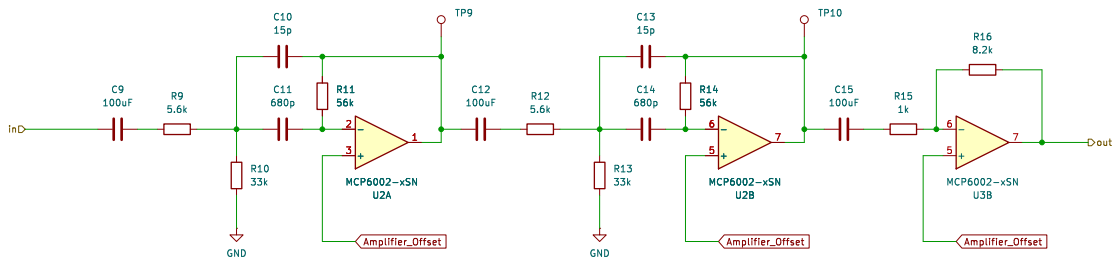
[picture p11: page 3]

hhrt@zhaw.ch
File: amplifier_filter_1channel.kicad_sch Sheet: /I_Amplifer/
Id: 4/6 Title: Amplifiers and Filters

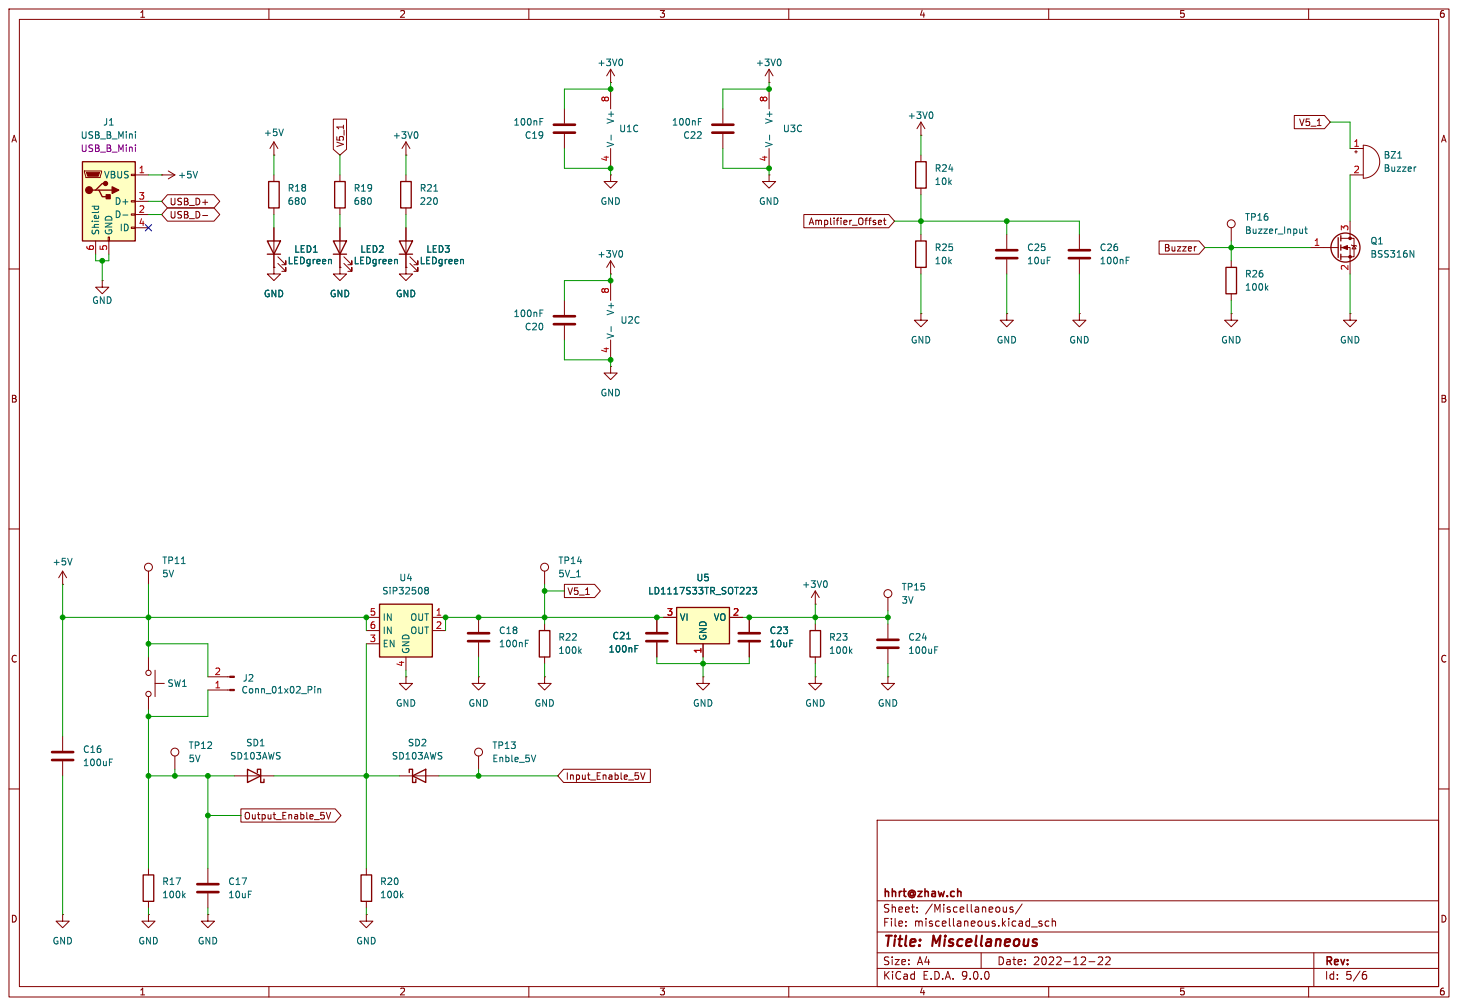
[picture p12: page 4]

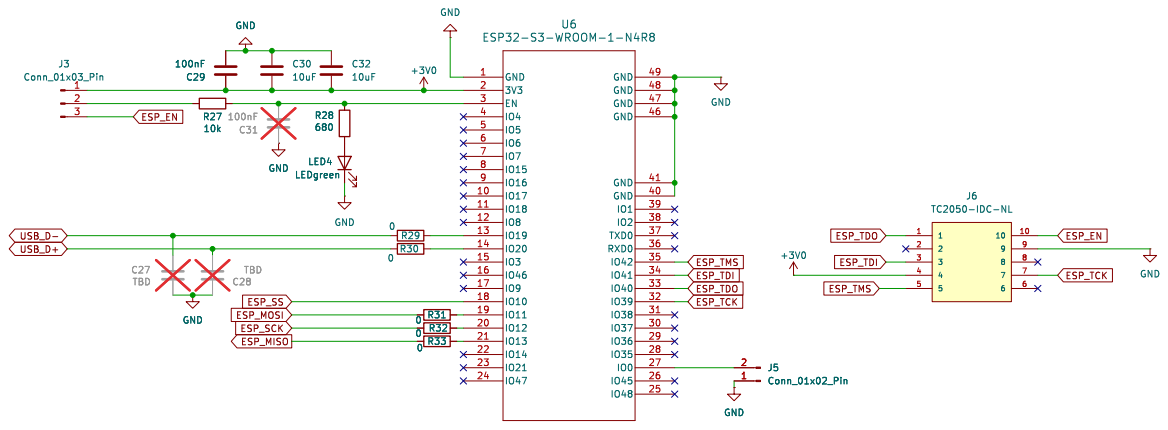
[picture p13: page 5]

Id: 6/6 Title: File: wlan_module.kicad_sch Sheet: /WLAN_module/

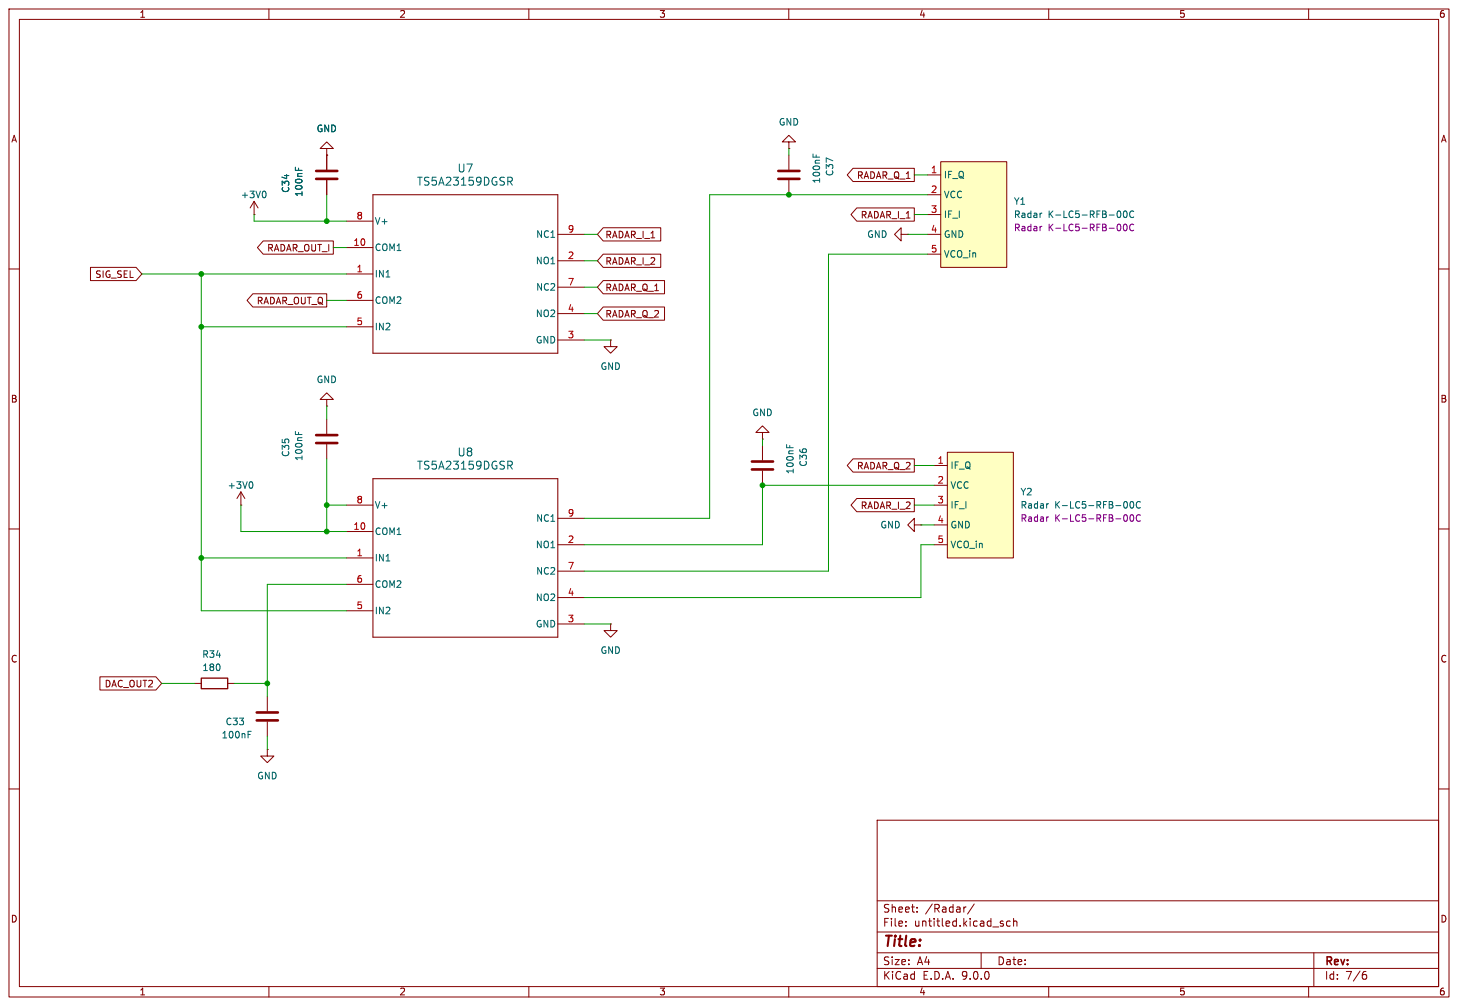
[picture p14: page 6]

Id: 7/6 Title: File: untitled.kicad_sch Sheet: /Radar/

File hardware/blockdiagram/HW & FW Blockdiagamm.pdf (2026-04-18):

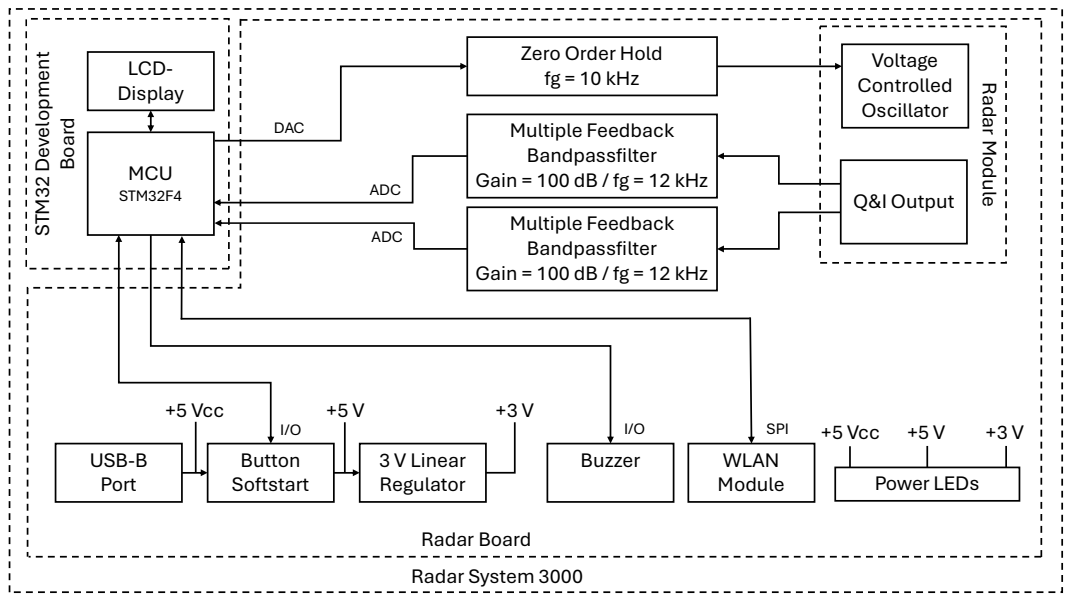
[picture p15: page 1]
STM32F4; LCD- Display; Button Softstart; USB-B Port; 3 V Linear Regulator; +5 Vcc; Power LEDs; Buzzer; +5 Vcc +5 V; Voltage Controlled Oscillator; Q&I Output; ADC; DAC; WLAN Module; SPI; Radar System 3000; Radar Board

Zero Order Hold
fg = 10 kHz

Radar Module STM32 Development Board MCU

Multiple Feedback
Bandpassfilter
Gain = 100 dB / fg = 12 kHz

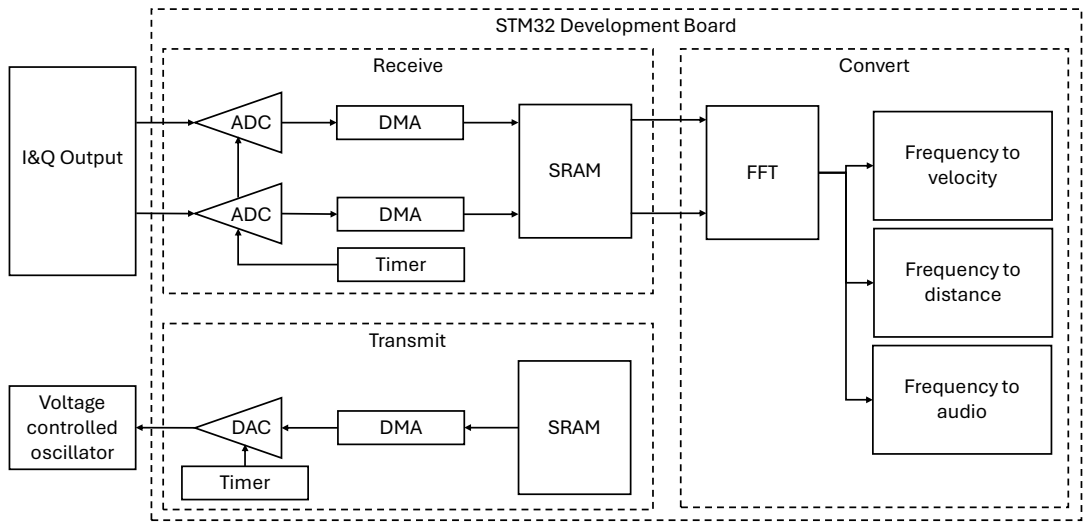
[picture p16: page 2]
STM32 Development Board; Receive; Transmit; Convert; DAC; ADC; Timer; DMA; Voltage controlled oscillator; I&Q Output; SRAM; FFT; Frequency to distance; Frequency to velocity; Frequency to audio

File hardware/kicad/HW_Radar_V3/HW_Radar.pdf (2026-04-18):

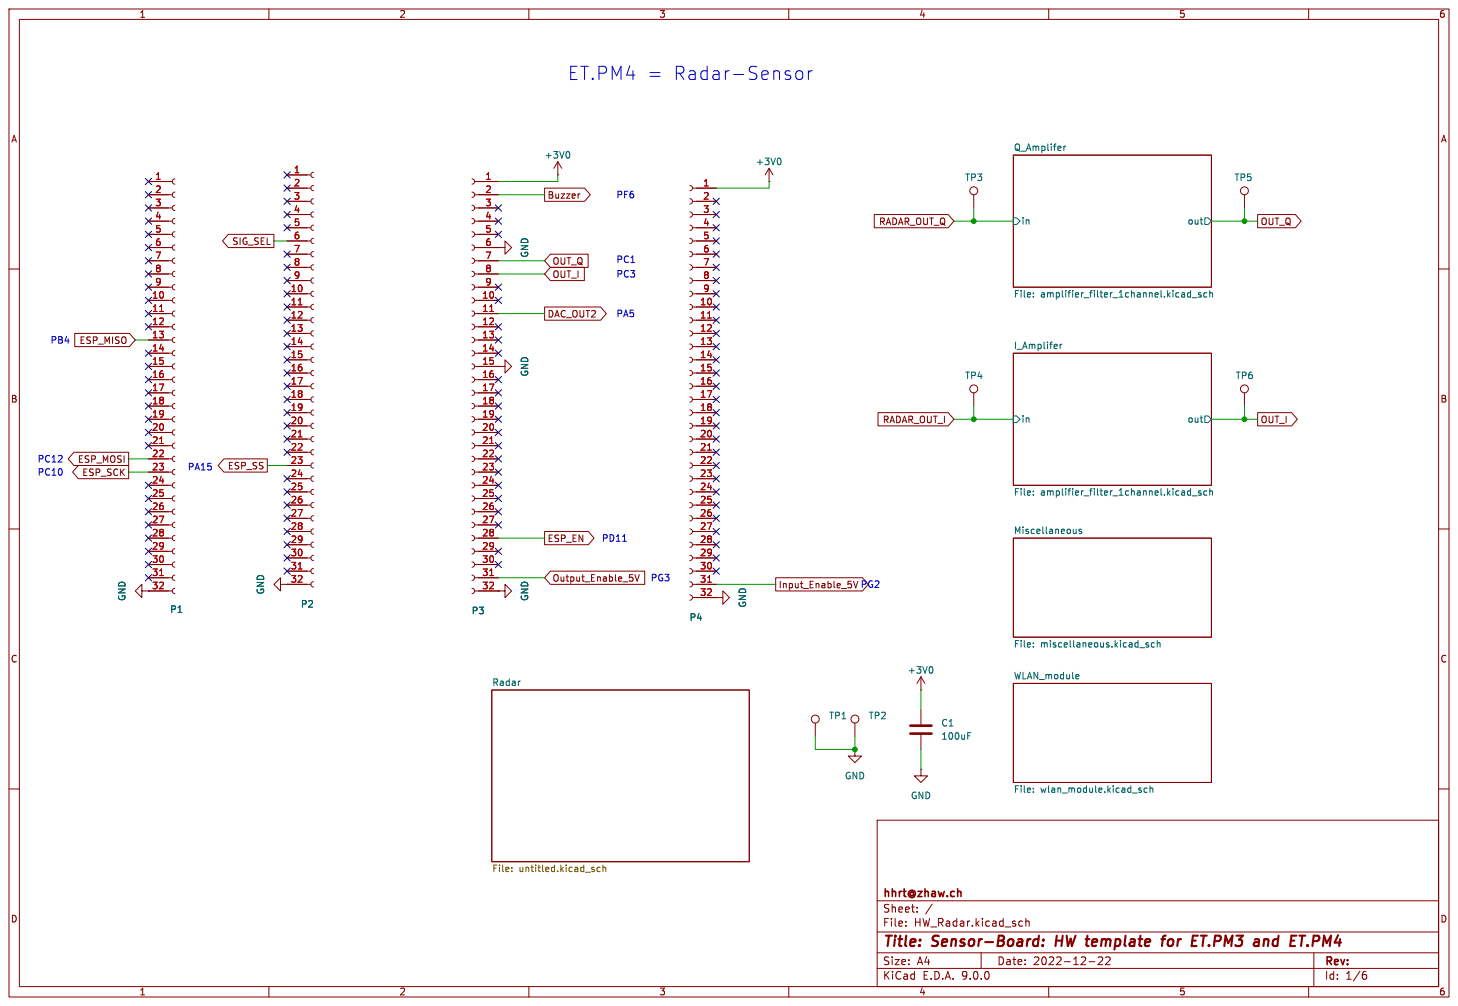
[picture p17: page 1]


hhrt@zhaw.ch
File: amplifier_filter_1channel.kicad_sch Sheet: /Q_Amplifer/
Id: 3/6 Title: Amplifiers and Filters


hhrt@zhaw.ch
File: amplifier_filter_1channel.kicad_sch Sheet: /I_Amplifer/
Id: 4/6 Title: Amplifiers and Filters


File: miscellaneous.kicad_sch Sheet: /Miscellaneous/ hhrt@zhaw.ch GND

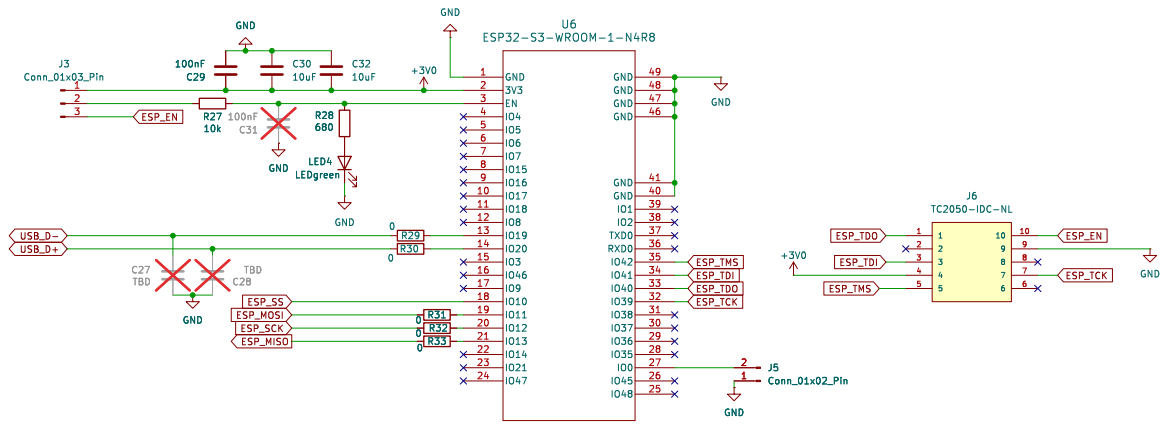
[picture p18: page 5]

Id: 6/6 Title: File: wlan_module.kicad_sch Sheet: /WLAN_module/


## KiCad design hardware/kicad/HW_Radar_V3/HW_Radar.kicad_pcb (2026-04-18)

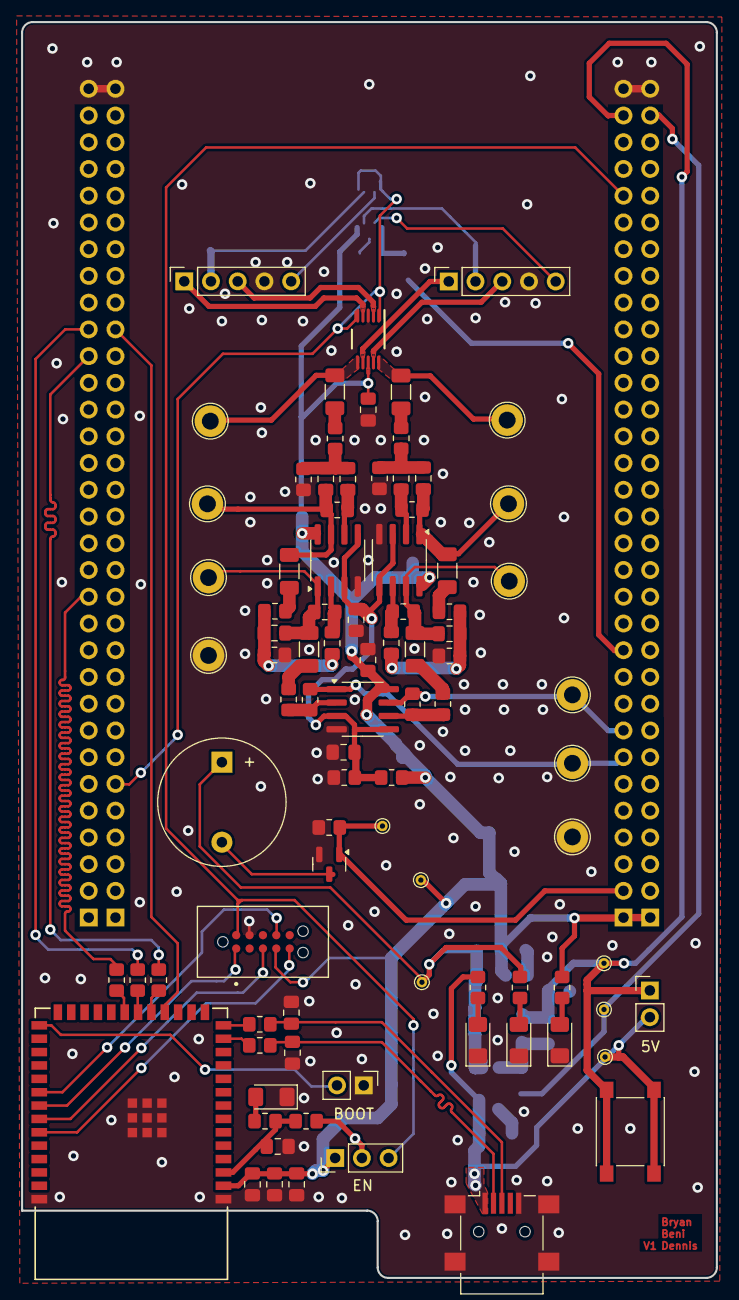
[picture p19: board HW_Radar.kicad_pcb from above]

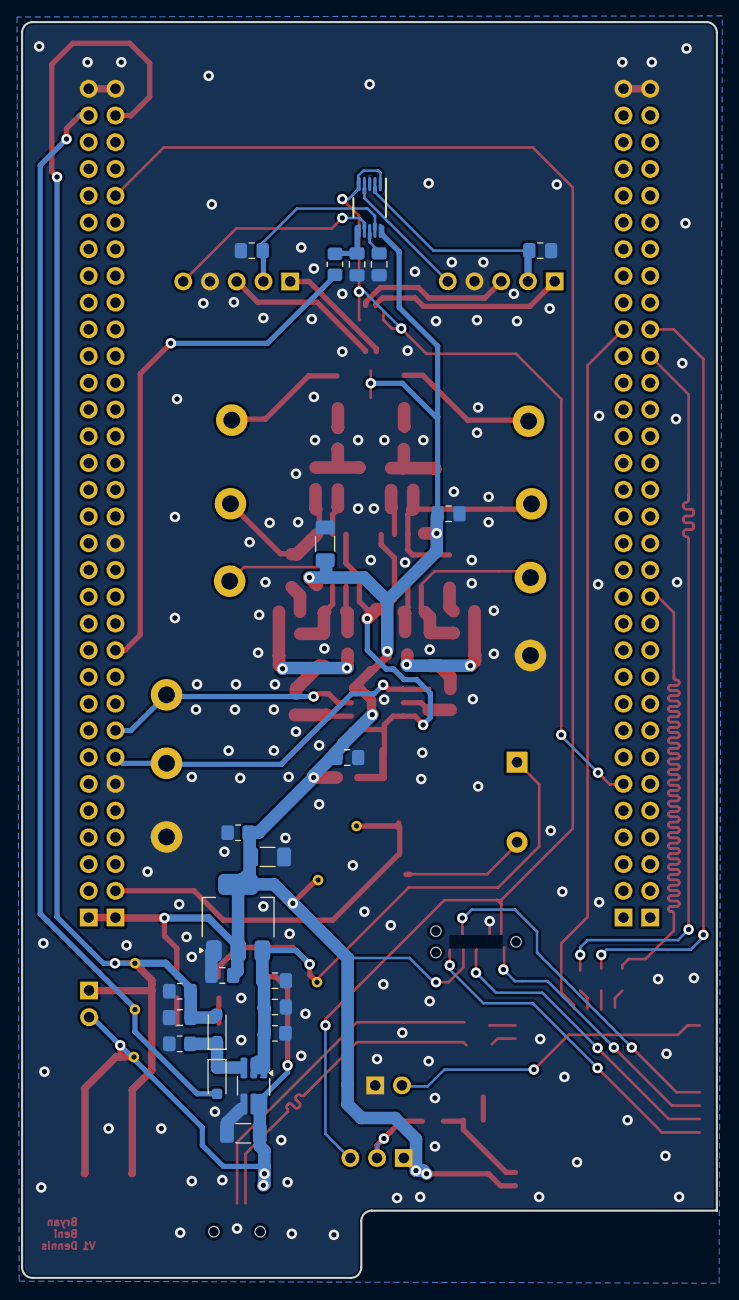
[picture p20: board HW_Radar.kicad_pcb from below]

Board: 2 copper layers, 66.0 x 119.3 mm, 115 parts (27 on the bottom side), 68 nets.

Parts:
1, 2, 3, 4, 6, 7, 8, 9, 10: TestPoint_Loop_D2.60mm_Drill1.6mm_Beaded
5: Q_Amplifer; TestPoint_Loop_D2.60mm_Drill1.6mm_Beaded
11, 12: 5V; TestPoint_THTPad_D1.0mm_Drill0.5mm
13: Enble_5V; TestPoint_THTPad_D1.0mm_Drill0.5mm
14: 5V_1; TestPoint_THTPad_D1.0mm_Drill0.5mm
15: 3V; TestPoint_THTPad_D1.0mm_Drill0.5mm
16: Buzzer_Input; TestPoint_THTPad_D1.0mm_Drill0.5mm
BZ1: Buzzer; Buzzer_12x9.5RM7.6
C1, C2, C5, C8, C9, C12, C15, C16, C24: 100uF; C_1206_3216Metric_Pad1.33x1.80mm_HandSolder
C3, C6, C10, C13: 15p; C_0805_2012Metric_Pad1.18x1.45mm_HandSolder
C4, C7, C11, C14: 680p; C_0805_2012Metric_Pad1.18x1.45mm_HandSolder
C17, C23, C25, C30, C32: 10uF; C_0805_2012Metric_Pad1.18x1.45mm_HandSolder
C18, C19, C20, C21, C22, C26, C29, C31, C33, C34, C35, C36, C37: 100nF; C_0805_2012Metric_Pad1.18x1.45mm_HandSolder
C27, C28: TBD; C_0805_2012Metric_Pad1.18x1.45mm_HandSolder
J1: USB_B_Mini; USB_Mini-B_Lumberg_2486_01_Horizontal
J2, J5: Conn_01x02_Pin; PinHeader_1x02_P2.54mm_Vertical
J3: Conn_01x03_Pin; PinHeader_1x03_P2.54mm_Vertical
J6: TC2050-IDC-NL; TAG-CONNECT_TC2050-IDC-NL
LED1, LED2, LED3, LED4: LEDgreen; LED_1206_3216Metric_Pad1.42x1.75mm_HandSolder
P1, P2, P3, P4: type="R" model="Conn_01x32_Female" lib=""; PinSocket_1x32_P2.54mm_Vertical
Q1: BSS316N; SOT-23
R1, R4, R9, R12: 5.6k; R_0805_2012Metric_Pad1.20x1.40mm_HandSolder
R2, R5, R10, R13: 33k; R_0805_2012Metric_Pad1.20x1.40mm_HandSolder
R3, R6, R11, R14: 56k; R_0805_2012Metric_Pad1.20x1.40mm_HandSolder
R7, R15: 1k; R_0805_2012Metric_Pad1.20x1.40mm_HandSolder
R8, R16: 8.2k; R_0805_2012Metric_Pad1.20x1.40mm_HandSolder
R17, R20, R22, R23, R26: 100k; R_0805_2012Metric_Pad1.20x1.40mm_HandSolder
R18, R19, R28: 680; R_0805_2012Metric_Pad1.20x1.40mm_HandSolder
R21: 220; R_0805_2012Metric_Pad1.20x1.40mm_HandSolder
R24, R25, R27: 10k; R_0805_2012Metric_Pad1.20x1.40mm_HandSolder
R29, R30, R31, R32, R33: 0; R_0805_2012Metric_Pad1.20x1.40mm_HandSolder
R34: 180; R_0805_2012Metric_Pad1.20x1.40mm_HandSolder
SD1, SD2: SD103AWS; D_SOD-323_HandSoldering
SW1: type="R" model="SW_Push" lib=""; SW_SPST_PTS645
U1, U2, U3: MCP6002-xSN; SOIC-8_3.9x4.9mm_P1.27mm
U4: SiP32508; TSOT-23-6_HandSoldering
U5: LD1117S33TR_SOT223; SOT-223-3_TabPin2
U6: ESP32-S3-WROOM-1-N4R8; ESP32-S3-WROOM-1_EXP
U7, U8: TS5A23159DGSR; DGS0010A_N
Y1, Y2: Radar K-LC5-RFB-00C; Radar_K-LC5

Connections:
+3V0: 15.1, C1.1, C19.2, C20.2, C22.2, C23.1, C24.1, C29.1, C30.2, C32.2, C34.2, C35.2, J3.1, J6.4, P3.1, P4.1, R21.1, R23.1, R24.2, U1.8 (V+), U2.8 (V+), U3.8 (V+), U5.2 (VO), U6.2 (3V3), U7.8 (V+), U8.8 (V+), U8.10 (COM1)
+5V: 11.1, C16.1, J1.1 (VBUS), J2.2, R18.1, SW1.1, U4.5 (IN), U4.6 (IN)
Amplifier_Offset: C25.1, C26.1, R24.1, R25.2, U1.3 (+), U1.5 (+), U2.3 (+), U2.5 (+), U3.3 (+), U3.5 (+)
Buzzer: 16.1, P3.2, Q1.1 (G), R26.1
DAC_OUT2: P3.11, R34.1
ESP_EN: J3.3, J6.10, P3.28
ESP_MISO: P1.13, R33.1
ESP_MOSI: P1.22, R31.1
ESP_SCK: P1.23, R32.1
ESP_SS: P2.23, U6.18 (IO10)
ESP_TCK: J6.7, U6.32 (IO39)
ESP_TDI: J6.3, U6.34 (IO41)
ESP_TDO: J6.1, U6.33 (IO40)
ESP_TMS: J6.5, U6.35 (IO42)
GND: 1.1, 2.1, C1.2, C16.2, C17.2, C18.2, C19.1, C20.1, C21.2, C22.1, C23.2, C24.2, C25.2, C26.2, C27.1, C28.1, C29.2, C30.1, C31.1, C32.1, C33.2, C34.1, C35.1, C36.2, C37.2, J1.5 (GND), J1.6 (Shield), J5.1, J6.9, LED1.1 (K), LED2.1 (K), LED3.1 (K), LED4.1 (K), P1.32, P2.32, P3.6, P3.15, P3.32, P4.32, Q1.2 (S), R2.1, R5.1, R10.1, R13.1, R17.2, R20.2, R22.2, R23.2, R25.1, R26.2, U1.4 (V-), U2.4 (V-), U3.4 (V-), U4.4 (GND), U5.1 (GND), U6.1 (GND), U6.40 (GND), U6.41 (GND), U6.42, U6.43, U6.44, U6.45, U6.46 (GND), U6.47 (GND), U6.48 (GND), U6.49 (GND), U7.3 (GND), U8.3 (GND), Y1.4 (GND), Y2.4 (GND)
Input_Enable_5V: 13.1, P4.31, SD2.2 (A)
unnamed: BZ1.2 (-), Q1.3 (D)
unnamed: C2.2, R1.1
unnamed: C3.1, C4.1, R1.2, R2.2
unnamed: 7.1, C3.2, C5.1, R3.2, U1.7
unnamed: C5.2, R4.1
unnamed: C6.1, C7.1, R4.2, R5.2
unnamed: 8.1, C6.2, C8.1, R6.2, U1.1
unnamed: C8.2, R7.1
unnamed: C9.2, R9.1
unnamed: C10.1, C11.1, R9.2, R10.2
unnamed: 9.1, C10.2, C12.1, R11.2, U2.1
unnamed: C12.2, R12.1
unnamed: C13.1, C14.1, R12.2, R13.2
unnamed: 10.1, C13.2, C15.1, R14.2, U2.7
unnamed: C15.2, R15.1
unnamed: J3.2, R27.1
unnamed: J5.2, U6.27 (IO0)
unnamed: LED1.2 (A), R18.2
unnamed: LED2.2 (A), R19.2
unnamed: LED3.2 (A), R21.2
unnamed: LED4.2 (A), R28.2
unnamed: R20.1, SD1.1 (K), SD2.1 (K), U4.3 (EN)
unnamed: C7.2, R6.1, U1.2 (-)
unnamed: C4.2, R3.1, U1.6 (-)
unnamed: C11.2, R11.1, U2.2 (-)
unnamed: C14.2, R14.1, U2.6 (-)
unnamed: R7.2, R8.1, U3.2 (-)
unnamed: R15.2, R16.1, U3.6 (-)
unnamed: C31.2, R27.2, R28.1, U6.3 (EN)
unnamed: R31.2, U6.19 (IO11)
unnamed: R32.2, U6.20 (IO12)
unnamed: R33.2, U6.21 (IO13)
unnamed: R29.2, U6.13 (IO19)
unnamed: R30.2, U6.14 (IO20)
unnamed: C33.1, R34.2, U8.6 (COM2)
unnamed: C37.1, U8.9 (NC1), Y1.2 (VCC)
unnamed: U8.7 (NC2), Y1.5 (VCO_in)
unnamed: C36.1, U8.2 (NO1), Y2.2 (VCC)
unnamed: U8.4 (NO2), Y2.5 (VCO_in)
OUT_I: 6.1, P3.8, R16.2, U3.7
OUT_Q: 5.1, P3.7, R8.2, U3.1
Output_Enable_5V: 12.1, C17.1, J2.1, P3.31, R17.1, SD1.2 (A), SW1.2
RADAR_I_1: U7.9 (NC1), Y1.3 (IF_I)
RADAR_I_2: U7.2 (NO1), Y2.3 (IF_I)
RADAR_OUT_I: 4.1, C9.1, U7.10 (COM1)
RADAR_OUT_Q: 3.1, C2.1, U7.6 (COM2)
RADAR_Q_1: U7.7 (NC2), Y1.1 (IF_Q)
RADAR_Q_2: U7.4 (NO2), Y2.1 (IF_Q)
SIG_SEL: P2.6, U7.1 (IN1), U7.5 (IN2), U8.1 (IN1), U8.5 (IN2)
USB_D+: C28.2, J1.3 (D+), R30.1
USB_D-: C27.2, J1.2 (D-), R29.1
V5_1: 14.1, BZ1.1 (+), C18.1, C21.1, R19.1, R22.1, U4.1 (OUT), U4.2 (OUT), U5.3 (VI)

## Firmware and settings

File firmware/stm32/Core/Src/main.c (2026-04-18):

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
/* Includes ------------------------------------------------------------------*/
#include "main.h"
#include "cmsis_os.h"
#include "app_touchgfx.h"
#include "error_handler.h"
#include "log.h"
#include "arm_math.h"
#include "timing.h"
#include "measurement.h"
#include "vco.h"
#include "shutdown_handler.h"
#include "buzzer_handler.h"
//#include "esp.h"
//#include "FreeRTOSConfig.h"


/* USER CODE BEGIN Includes */
#include "Components/ili9341/ili9341.h"
/* USER CODE END Includes */

/* USER CODE BEGIN PD */
#define REFRESH_COUNT           ((uint32_t)1386)   /* SDRAM refresh counter */
#define SDRAM_TIMEOUT           ((uint32_t)0xFFFF)

/**
 * @brief  FMC SDRAM Mode definition register defines
 */
#define SDRAM_MODEREG_BURST_LENGTH_1             ((uint16_t)0x0000)
#define SDRAM_MODEREG_BURST_LENGTH_2             ((uint16_t)0x0001)
#define SDRAM_MODEREG_BURST_LENGTH_4             ((uint16_t)0x0002)
#define SDRAM_MODEREG_BURST_LENGTH_8             ((uint16_t)0x0004)
#define SDRAM_MODEREG_BURST_TYPE_SEQUENTIAL      ((uint16_t)0x0000)
#define SDRAM_MODEREG_BURST_TYPE_INTERLEAVED     ((uint16_t)0x0008)
#define SDRAM_MODEREG_CAS_LATENCY_2              ((uint16_t)0x0020)
#define SDRAM_MODEREG_CAS_LATENCY_3              ((uint16_t)0x0030)
#define SDRAM_MODEREG_OPERATING_MODE_STANDARD    ((uint16_t)0x0000)
#define SDRAM_MODEREG_WRITEBURST_MODE_PROGRAMMED ((uint16_t)0x0000)
#define SDRAM_MODEREG_WRITEBURST_MODE_SINGLE     ((uint16_t)0x0200)

#define I2C3_TIMEOUT_MAX                    0x3000 /*<! The value of the maximal timeout for I2C waiting loops */
#define SPI5_TIMEOUT_MAX                    0x1000
/* USER CODE END PD */

/* USER CODE BEGIN PM */
Timing_HandleTypeDef_t htiming;
MEAS_HandleTypeDef_t hmeas;
VCO_HandleTypeDef_t hvco;
STDWN_HandleTypeDef_t hstdwn;
BUZ_HandleTypeDef_t hbuz;
/* USER CODE END PM */

ADC_HandleTypeDef hadc1;
ADC_HandleTypeDef hadc2;
DMA_HandleTypeDef hdma_adc1;

CRC_HandleTypeDef hcrc;

DAC_HandleTypeDef hdac;
DMA_HandleTypeDef hdma_dac2;

DMA2D_HandleTypeDef hdma2d;

I2C_HandleTypeDef hi2c3;

LTDC_HandleTypeDef hltdc;

RTC_HandleTypeDef hrtc;

SPI_HandleTypeDef hspi3;
SPI_HandleTypeDef hspi5;
DMA_HandleTypeDef hdma_spi3_tx;
DMA_HandleTypeDef hdma_spi3_rx;

TIM_HandleTypeDef htim2;
TIM_HandleTypeDef htim8;
TIM_HandleTypeDef htim10;

UART_HandleTypeDef huart1;
DMA_HandleTypeDef hdma_usart1_tx;

DMA_HandleTypeDef hdma_memtomem_dma2_stream1;
SDRAM_HandleTypeDef hsdram1;

/* Definitions for defaultTask */
osThreadId_t defaultTaskHandle;
const osThreadAttr_t defaultTask_attributes = { .name = "defaultTask",
		.stack_size = 128 * 4, .priority = (osPriority_t) osPriorityNormal, };
/* Definitions for GUI_Task */
osThreadId_t GUI_TaskHandle;
const osThreadAttr_t GUI_Task_attributes = { .name = "GUI_Task", .stack_size =
		8192 * 4, .priority = (osPriority_t) osPriorityNormal, };
/* USER CODE BEGIN PV */
osThreadId_t SAMPLING_TaskHandle;
const osThreadAttr_t SAMPLING_Task_attributes = { .name = "SAMPLING_Task", .stack_size =
		8192, .priority = (osPriority_t) osPriorityHigh, };
/* USER CODE END PV */

void SystemClock_Config(void);
static void MX_GPIO_Init(void);
static void MX_DMA_Init(void);
static void MX_CRC_Init(void);
static void MX_I2C3_Init(void);
static void MX_SPI5_Init(void);
static void MX_FMC_Init(void);
static void MX_LTDC_Init(void);
static void MX_DMA2D_Init(void);
static void MX_SPI3_Init(void);
static void MX_USART1_UART_Init(void);
void StartDefaultTask(void *argument);
extern void TouchGFX_Task(void *argument);
void Sampling_Task(void *argument);
/* USER CODE BEGIN PFP */
static void BSP_SDRAM_Initialization_Sequence(SDRAM_HandleTypeDef *hsdram,
		FMC_SDRAM_CommandTypeDef *Command);

static uint8_t I2C3_ReadData(uint8_t Addr, uint8_t Reg);
static void I2C3_WriteData(uint8_t Addr, uint8_t Reg, uint8_t Value);
static uint8_t I2C3_ReadBuffer(uint8_t Addr, uint8_t Reg, uint8_t *pBuffer,
		uint16_t Length);

/* SPIx bus function */
static void SPI5_Write(uint16_t Value);
static uint32_t SPI5_Read(uint8_t ReadSize);
static void SPI5_Error(void);

/* Link function for LCD peripheral */
void LCD_IO_Init(void);
void LCD_IO_WriteData(uint16_t RegValue);
void LCD_IO_WriteReg(uint8_t Reg);
uint32_t LCD_IO_ReadData(uint16_t RegValue, uint8_t ReadSize);
void LCD_Delay(uint32_t delay);

/* IOExpander IO functions */
void IOE_Init(void);
void IOE_ITConfig(void);
void IOE_Delay(uint32_t Delay);
void IOE_Write(uint8_t Addr, uint8_t Reg, uint8_t Value);
uint8_t IOE_Read(uint8_t Addr, uint8_t Reg);
uint16_t IOE_ReadMultiple(uint8_t Addr, uint8_t Reg, uint8_t *pBuffer,
		uint16_t Length);

/* USER CODE END PFP */

/* USER CODE BEGIN 0 */
static LCD_DrvTypeDef *LcdDrv;

uint32_t I2c3Timeout = I2C3_TIMEOUT_MAX; /*<! Value of Timeout when I2C communication fails */
uint32_t Spi5Timeout = SPI5_TIMEOUT_MAX; /*<! Value of Timeout when SPI communication fails */
/* USER CODE END 0 */

/**
 * @brief  The application entry point.
 * @retval int
 */
int main(void) {

	/* USER CODE BEGIN 1 */

	                 // Enable CYCCNT
	/* USER CODE END 1 */

	/* MCU Configuration--------------------------------------------------------*/

	/* Reset of all peripherals, Initializes the Flash interface and the Systick. */
	HAL_Init();

	/* Configure the system clock */
	SystemClock_Config();

	/* Initialize all configured peripherals */
	MX_GPIO_Init();
	sys_init_shutdown(&hstdwn, &hrtc);
	MX_DMA_Init();
	MX_CRC_Init();
	MX_I2C3_Init();
	MX_SPI5_Init();
	MX_FMC_Init();
	MX_LTDC_Init();
	MX_DMA2D_Init();
	MX_SPI3_Init();
	MX_USART1_UART_Init();
	MX_TouchGFX_Init();
	/* Call PreOsInit function */
	MX_TouchGFX_PreOSInit();
	/* USER CODE BEGIN 2 */
	Timing_Init(&htiming, &htim2, &htim8);
	VCO_Init(&hvco, &hdac, 256, DAC_TRIGGER_T8_TRGO);
	meas_init(&hmeas, &hadc1, &hadc2);
	//buzzer_init(&htim10, &hbuz);

	/* USER CODE END 2 */

	/* Init scheduler */
	osKernelInitialize();

	/* USER CODE BEGIN RTOS_MUTEX */
	/* add mutexes, ... */
	/* USER CODE END RTOS_MUTEX */

	/* USER CODE BEGIN RTOS_SEMAPHORES */
	/* add semaphores, ... */
	/* USER CODE END RTOS_SEMAPHORES */

	/* USER CODE BEGIN RTOS_TIMERS */
	/* start timers, add new ones, ... */
	/* USER CODE END RTOS_TIMERS */

	/* USER CODE BEGIN RTOS_QUEUES */
	/* add queues, ... */
	/* USER CODE END RTOS_QUEUES */

	/* Create the thread(s) */
	/* creation of defaultTask */
	defaultTaskHandle = osThreadNew(StartDefaultTask, NULL,
			&defaultTask_attributes);

	/* creation of GUI_Task */
	GUI_TaskHandle = osThreadNew(TouchGFX_Task, NULL, &GUI_Task_attributes);

	SAMPLING_TaskHandle = osThreadNew(Sampling_Task, NULL, &SAMPLING_Task_attributes);

	Log_init(huart1);
	/* USER CODE BEGIN RTOS_THREADS */


	/* add threads, ... */
	/* USER CODE END RTOS_THREADS */

	/* USER CODE BEGIN RTOS_EVENTS */
	/* add events, ... */
	/* USER CODE END RTOS_EVENTS */

	/* Start scheduler */
	osKernelStart();

	/* We should never get here as control is now taken by the scheduler */

	/* Infinite loop */
	/* USER CODE BEGIN WHILE */
	while (1) {
		/* USER CODE END WHILE */

		/* USER CODE BEGIN 3 */
	}
	/* USER CODE END 3 */
}

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
/* USER CODE BEGIN 4 */
/**
 * @brief  Perform the SDRAM external memory initialization sequence
 * @param  hsdram: SDRAM handle
 * @param  Command: Pointer to SDRAM command structure
 * @retval None
 */
static void BSP_SDRAM_Initialization_Sequence(SDRAM_HandleTypeDef *hsdram,
		FMC_SDRAM_CommandTypeDef *Command) {
	__IO uint32_t tmpmrd = 0;

	/* Step 1:  Configure a clock configuration enable command */
	Command->CommandMode = FMC_SDRAM_CMD_CLK_ENABLE;
	Command->CommandTarget = FMC_SDRAM_CMD_TARGET_BANK2;
	Command->AutoRefreshNumber = 1;
	Command->ModeRegisterDefinition = 0;

	/* Send the command */
	HAL_SDRAM_SendCommand(hsdram, Command, SDRAM_TIMEOUT);

	/* Step 2: Insert 100 us minimum delay */
	/* Inserted delay is equal to 1 ms due to systick time base unit (ms) */
	HAL_Delay(1);

	/* Step 3: Configure a PALL (precharge all) command */
	Command->CommandMode = FMC_SDRAM_CMD_PALL;
	Command->CommandTarget = FMC_SDRAM_CMD_TARGET_BANK2;
	Command->AutoRefreshNumber = 1;
	Command->ModeRegisterDefinition = 0;

	/* Send the command */
	HAL_SDRAM_SendCommand(hsdram, Command, SDRAM_TIMEOUT);

	/* Step 4: Configure an Auto Refresh command */
	Command->CommandMode = FMC_SDRAM_CMD_AUTOREFRESH_MODE;
	Command->CommandTarget = FMC_SDRAM_CMD_TARGET_BANK2;
	Command->AutoRefreshNumber = 4;
	Command->ModeRegisterDefinition = 0;

	/* Send the command */
	HAL_SDRAM_SendCommand(hsdram, Command, SDRAM_TIMEOUT);

	/* Step 5: Program the external memory mode register */
	tmpmrd = (uint32_t) SDRAM_MODEREG_BURST_LENGTH_1 |
	SDRAM_MODEREG_BURST_TYPE_SEQUENTIAL |
	SDRAM_MODEREG_CAS_LATENCY_3 |
	SDRAM_MODEREG_OPERATING_MODE_STANDARD |
	SDRAM_MODEREG_WRITEBURST_MODE_SINGLE;

	Command->CommandMode = FMC_SDRAM_CMD_LOAD_MODE;
	Command->CommandTarget = FMC_SDRAM_CMD_TARGET_BANK2;
	Command->AutoRefreshNumber = 1;
	Command->ModeRegisterDefinition = tmpmrd;

	/* Send the command */
	HAL_SDRAM_SendCommand(hsdram, Command, SDRAM_TIMEOUT);

	/* Step 6: Set the refresh rate counter */
	/* Set the device refresh rate */
	HAL_SDRAM_ProgramRefreshRate(hsdram, REFRESH_COUNT);
}

/**
 * @brief  IOE Low Level Initialization.
 */
void IOE_Init(void) {
	//Dummy function called when initializing to stmpe811 to setup the i2c.
	//This is done with cubmx and is therfore not done here.
}

/**
 * @brief  IOE Low Level Interrupt configuration.
 */
void IOE_ITConfig(void) {
	//Dummy function called when initializing to stmpe811 to setup interupt for the i2c.
	//The interupt is not used in our case, therefore nothing is done here.
}

/**
 * @brief  IOE Writes single data operation.
 * @param  Addr: I2C Address
 * @param  Reg: Reg Address
 * @param  Value: Data to be written
 */
void IOE_Write(uint8_t Addr, uint8_t Reg, uint8_t Value) {
	I2C3_WriteData(Addr, Reg, Value);
}

/**
 * @brief  IOE Reads single data.
 * @param  Addr: I2C Address
 * @param  Reg: Reg Address
 * @retval The read data
 */
uint8_t IOE_Read(uint8_t Addr, uint8_t Reg) {
	return I2C3_ReadData(Addr, Reg);
}

/**
 * @brief  IOE Reads multiple data.
 * @param  Addr: I2C Address
 * @param  Reg: Reg Address
 * @param  pBuffer: pointer to data buffer
 * @param  Length: length of the data
 * @retval 0 if no problems to read multiple data
 */
uint16_t IOE_ReadMultiple(uint8_t Addr, uint8_t Reg, uint8_t *pBuffer,
		uint16_t Length) {
	return I2C3_ReadBuffer(Addr, Reg, pBuffer, Length);
}

/**
 * @brief  IOE Delay.
 * @param  Delay in ms
 */
void IOE_Delay(uint32_t Delay) {
	HAL_Delay(Delay);
}

/**
 * @brief  Writes a value in a register of the device through BUS.
 * @param  Addr: Device address on BUS Bus.
 * @param  Reg: The target register address to write
 * @param  Value: The target register value to be written
 */
static void I2C3_WriteData(uint8_t Addr, uint8_t Reg, uint8_t Value) {
	HAL_StatusTypeDef status = HAL_OK;

	status = HAL_I2C_Mem_Write(&hi2c3, Addr, (uint16_t) Reg,
			I2C_MEMADD_SIZE_8BIT, &Value, 1, I2c3Timeout);

	/* Check the communication status */
	if (status != HAL_OK) {
		/* Re-Initialize the BUS */
		//I2Cx_Error();
	}
}

/**
 * @brief  Reads a register of the device through BUS.
 * @param  Addr: Device address on BUS Bus.
 * @param  Reg: The target register address to write
 * @retval Data read at register address
 */
static uint8_t I2C3_ReadData(uint8_t Addr, uint8_t Reg) {
	HAL_StatusTypeDef status = HAL_OK;
	uint8_t value = 0;

	status = HAL_I2C_Mem_Read(&hi2c3, Addr, Reg, I2C_MEMADD_SIZE_8BIT, &value,
			1, I2c3Timeout);

	/* Check the communication status */
	if (status != HAL_OK) {
		/* Re-Initialize the BUS */
		//I2Cx_Error();
	}
	return value;
}

/**
 * @brief  Reads multiple data on the BUS.
 * @param  Addr: I2C Address
 * @param  Reg: Reg Address
 * @param  pBuffer: pointer to read data buffer
 * @param  Length: length of the data
 * @retval 0 if no problems to read multiple data
 */
static uint8_t I2C3_ReadBuffer(uint8_t Addr, uint8_t Reg, uint8_t *pBuffer,
		uint16_t Length) {
	HAL_StatusTypeDef status = HAL_OK;

	status = HAL_I2C_Mem_Read(&hi2c3, Addr, (uint16_t) Reg,
			I2C_MEMADD_SIZE_8BIT, pBuffer, Length, I2c3Timeout);

	/* Check the communication status */
	if (status == HAL_OK) {
		return 0;
	} else {
		/* Re-Initialize the BUS */
		//I2Cx_Error();
		return 1;
	}
}

/**
 * @brief  Reads 4 bytes from device.
 * @param  ReadSize: Number of bytes to read (max 4 bytes)
 * @retval Value read on the SPI
 */
static uint32_t SPI5_Read(uint8_t ReadSize) {
	HAL_StatusTypeDef status = HAL_OK;
	uint32_t readvalue;

	status = HAL_SPI_Receive(&hspi5, (uint8_t*) &readvalue, ReadSize,
			Spi5Timeout);

	/* Check the communication status */
	if (status != HAL_OK) {
		/* Re-Initialize the BUS */
		SPI5_Error();
	}

	return readvalue;
}

/**
 * @brief  Writes a byte to device.
 * @param  Value: value to be written
 */
static void SPI5_Write(uint16_t Value) {
	HAL_StatusTypeDef status = HAL_OK;

	status = HAL_SPI_Transmit(&hspi5, (uint8_t*) &Value, 1, Spi5Timeout);

	/* Check the communication status */
	if (status != HAL_OK) {
		/* Re-Initialize the BUS */
		SPI5_Error();
	}
}

/**
 * @brief  SPI5 error treatment function.
 */
static void SPI5_Error(void) {
	/* De-initialize the SPI communication BUS */
	//HAL_SPI_DeInit(&SpiHandle);
	/* Re- Initialize the SPI communication BUS */
	//SPIx_Init();
}

void LCD_IO_Init(void) {
	/* Set or Reset the control line */
	HAL_GPIO_WritePin(GPIOC, GPIO_PIN_2, GPIO_PIN_RESET);
	HAL_GPIO_WritePin(GPIOC, GPIO_PIN_2, GPIO_PIN_SET);
}

/**
 * @brief  Writes register value.
 */
void LCD_IO_WriteData(uint16_t RegValue) {
	/* Set WRX to send data */
	HAL_GPIO_WritePin(GPIOD, GPIO_PIN_13, GPIO_PIN_SET);

	/* Reset LCD control line(/CS) and Send data */
	HAL_GPIO_WritePin(GPIOC, GPIO_PIN_2, GPIO_PIN_RESET);
	SPI5_Write(RegValue);

	/* Deselect: Chip Select high */
	HAL_GPIO_WritePin(GPIOC, GPIO_PIN_2, GPIO_PIN_SET);
}

/**
 * @brief  Writes register address.
 */
void LCD_IO_WriteReg(uint8_t Reg) {
	/* Reset WRX to send command */
	HAL_GPIO_WritePin(GPIOD, GPIO_PIN_13, GPIO_PIN_RESET);

	/* Reset LCD control line(/CS) and Send command */
	HAL_GPIO_WritePin(GPIOC, GPIO_PIN_2, GPIO_PIN_RESET);
	SPI5_Write(Reg);

	/* Deselect: Chip Select high */
	HAL_GPIO_WritePin(GPIOC, GPIO_PIN_2, GPIO_PIN_SET);
}

/**
 * @brief  Reads register value.
 * @param  RegValue Address of the register to read
 * @param  ReadSize Number of bytes to read
 * @retval Content of the register value
 */
uint32_t LCD_IO_ReadData(uint16_t RegValue, uint8_t ReadSize) {
	uint32_t readvalue = 0;

	/* Select: Chip Select low */
	HAL_GPIO_WritePin(GPIOC, GPIO_PIN_2, GPIO_PIN_RESET);

	/* Reset WRX to send command */
	HAL_GPIO_WritePin(GPIOD, GPIO_PIN_13, GPIO_PIN_RESET);

	SPI5_Write(RegValue);

	readvalue = SPI5_Read(ReadSize);

	/* Set WRX to send data */
	HAL_GPIO_WritePin(GPIOD, GPIO_PIN_13, GPIO_PIN_SET);

	/* Deselect: Chip Select high */
	HAL_GPIO_WritePin(GPIOC, GPIO_PIN_2, GPIO_PIN_SET);

	return readvalue;
}

/**
 * @brief  Wait for loop in ms.
 * @param  Delay in ms.
 */
void LCD_Delay(uint32_t Delay) {
	HAL_Delay(Delay);
}

/* USER CODE END 4 */

/* USER CODE BEGIN Header_StartDefaultTask */
/**
 * @brief  Function implementing the defaultTask thread.
 * @param  argument: Not used
 * @retval None
 */
/* USER CODE END Header_StartDefaultTask */
void StartDefaultTask(void *argument) {
	/* USER CODE BEGIN 5 */

	/* Infinite loop */
	for (;;) {
		sys_check_shutdown(&hstdwn);
		osDelay(100);
	}
	/* USER CODE END 5 */
}
void dwt_enable_cycle_counter(void)
{
    // Check if already enabled
    if (!(CoreDebug->DEMCR & CoreDebug_DEMCR_TRCENA_Msk))
        CoreDebug->DEMCR |= CoreDebug_DEMCR_TRCENA_Msk;

    // Reset the counter before enabling
    DWT->CYCCNT = 0;

    // Enable the cycle counter if not already on
    if (!(DWT->CTRL & DWT_CTRL_CYCCNTENA_Msk))
        DWT->CTRL |= DWT_CTRL_CYCCNTENA_Msk;
    for (volatile int i = 0; i < 1000; ++i);
    DWT->CYCCNT = 0;

}

Error_t start_sequence(){

	exec(VCO_start(&hvco));
	dwt_enable_cycle_counter();
	exec(Timing_start_seq(&htiming));
	exec(meas_start_Sampling(&hmeas));

	//uint32_t stop = DWT->CYCCNT;
	//volatile uint32_t delay = cycles2-cycles;
	RETURN_OK();
}
Error_t stop_sequence(){
	hmeas.state = MEAS_WAITING;
	exec(meas_stop_Sampling(&hmeas));
	exec(Timing_stop_seq(&htiming));
	exec(VCO_stop(&hvco));

	RETURN_OK();
}

void Sampling_Task(void *argument) {
	/* USER CODE BEGIN 5 */
	logMsg(LOG_INFO, "hello");
	meas_setTaskHandle(SAMPLING_TaskHandle);
	exec(start_sequence());



	/* Infinite loop */
	for (;;) {
		ulTaskNotifyTake(pdTRUE, portMAX_DELAY);
		meas_task(&hmeas);
		if(hmeas.data.fft_buf_index == 3){
			float32_t *data_to_send = &hmeas.data.fft_buf[0]; // first frame
			HAL_UART_Transmit_DMA(&huart1, (uint8_t *)data_to_send, sizeof(float32_t) * MEAS_SAMPLE_BUFFER_LENGTH/2);
		}
	}
	/* USER CODE END 5 */
}


/**
 * @brief  Period elapsed callback in non blocking mode
 * @note   This function is called  when TIM6 interrupt took place, inside
 * HAL_TIM_IRQHandler(). It makes a direct call to HAL_IncTick() to increment
 * a global variable "uwTick" used as application time base.
 * @param  htim : TIM handle
 * @retval None
 */
void HAL_TIM_PeriodElapsedCallback(TIM_HandleTypeDef *htim) {
	if (htim->Instance == TIM6) {
		HAL_IncTick();
	}
}

/**
 * @brief  This function is executed in case of error occurrence.
 * @retval None
 */
void Error_Handler(void) {
	/* USER CODE BEGIN Error_Handler_Debug */
	/* User can add his own implementation to report the HAL error return state */

	/* USER CODE END Error_Handler_Debug */
}

#ifdef  USE_FULL_ASSERT
/**
  * @brief  Reports the name of the source file and the source line number
  *         where the assert_param error has occurred.
  * @param  file: pointer to the source file name
  * @param  line: assert_param error line source number
  * @retval None
  */
void assert_failed(uint8_t *file, uint32_t line)
{
  /* USER CODE BEGIN 6 */
  /* User can add his own implementation to report the file name and line number,
     tex: printf("Wrong parameters value: file %s on line %d\r\n", file, line) */
  /* USER CODE END 6 */
}
#endif /* USE_FULL_ASSERT */

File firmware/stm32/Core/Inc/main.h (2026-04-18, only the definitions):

#define VSYNC_FREQ_Pin GPIO_PIN_2
#define VSYNC_FREQ_GPIO_Port GPIOE
#define RENDER_TIME_Pin GPIO_PIN_3
#define RENDER_TIME_GPIO_Port GPIOE
#define FRAME_RATE_Pin GPIO_PIN_4
#define FRAME_RATE_GPIO_Port GPIOE
#define MCU_ACTIVE_Pin GPIO_PIN_5
#define MCU_ACTIVE_GPIO_Port GPIOE
#define SIG_SEL_Pin GPIO_PIN_13
#define SIG_SEL_GPIO_Port GPIOC
#define BUZZER_Pin GPIO_PIN_6
#define BUZZER_GPIO_Port GPIOF
#define SIGNAL_Q_Pin GPIO_PIN_1
#define SIGNAL_Q_GPIO_Port GPIOC
#define SIGNAL_I_Pin GPIO_PIN_3
#define SIGNAL_I_GPIO_Port GPIOC
#define VCO_Pin GPIO_PIN_5
#define VCO_GPIO_Port GPIOA
#define ESP_EN_Pin GPIO_PIN_11
#define ESP_EN_GPIO_Port GPIOD
#define EN_PCB_OUT_Pin GPIO_PIN_2
#define EN_PCB_OUT_GPIO_Port GPIOG
#define EN_PCB_IN_Pin GPIO_PIN_3
#define EN_PCB_IN_GPIO_Port GPIOG

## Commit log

2026-04-18 Initial commit: ZHAW PM4 Doppler radar detector
    Team project: CW Doppler radar with STM32F429 + ESP32, analog
    signal conditioning, DMA-driven acquisition, CMSIS-DSP FFT + CFAR,
    TouchGFX live UI, FastAPI backend, YOLOv8 angle-of-arrival sensor
    fusion desktop app.
    [HW_Radar.kicad_pcb, HW_Radar.kicad_sch, PARTS_ORDER_FORM.xls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]
2026-04-18 Add schematic PDF, higher-quality block diagram, MCU data-path figure
    - docs/schematic.pdf: KiCad schematic export of the custom radar board
    - docs/block-diagram.png: replaced with the detailed system-level diagram
    - docs/mcu-data-path.png: signal-flow figure showing Dual-ADC → DMA →
    SRAM → FFT plus the DAC/VCO transmit branch
    - README.md: reference the new figures and schematic

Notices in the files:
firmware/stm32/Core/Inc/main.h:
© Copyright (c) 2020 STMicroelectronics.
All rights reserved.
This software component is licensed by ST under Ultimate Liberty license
